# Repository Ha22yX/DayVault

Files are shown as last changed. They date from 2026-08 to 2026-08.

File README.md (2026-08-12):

<h1 align="center">DayVault</h1>

<p align="center">
  A compact wearable recorder that captures everyday speech as Ogg Opus files and transfers them to a local life archive.
</p>

<p align="center">
  <a href="README.zh-CN.md">简体中文</a> ·
  <a href="https://github.com/Ha22yX/DayVault/releases/latest">Latest release</a> ·
  <a href="Docs/README.md">Hardware docs</a> ·
  <a href="tools/dayvault_sync/README.md">Sync app</a> ·
  <a href="Docs/Serial-Command-Reference.md">Protocol</a>
</p>

<p align="center">
  
  
  
  
  
</p>

<table>
  <tr>
    <td width="50%" align="center">
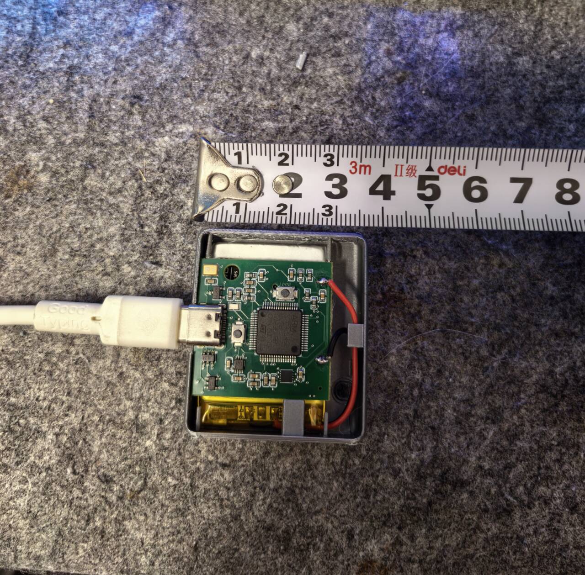
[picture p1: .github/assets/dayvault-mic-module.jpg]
Assembled DayVault recorder prototype with PCB, battery, and printed enclosure
      
      <br />
      <strong>Working hardware prototype</strong><br />
      STM32 board, battery, USB-C, microSD, and a lightweight printed enclosure.
    </td>
    <td width="50%" align="center">
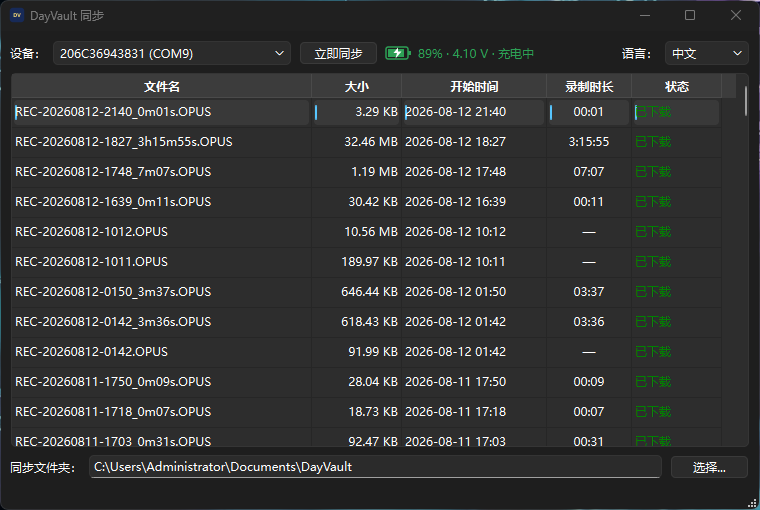
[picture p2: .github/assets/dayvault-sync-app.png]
DayVault Sync showing recordings, battery voltage, and charging state
      
      <br />
      <strong>Windows sync app</strong><br />
      Newest-first recordings, readable sizes, duration, battery level, and charging state.
    </td>
  </tr>
</table>

## What DayVault Does

DayVault is a complete personal audio-recording chain:

1. Two PDM microphones capture speech from opposite sides of a chest-worn device.
2. STM32L452 firmware adaptively fuses both channels into one 16 kHz mono stream.
3. Audio is encoded directly to Ogg Opus at a target 24 kbit/s and stored on microSD.
4. The Windows app detects the device over USB and synchronizes recordings into a folder for transcription and archiving.

No parallel WAV or raw PCM copy is kept during normal recording. At 24 kbit/s, continuous audio is roughly 260 MB per day before filesystem overhead.

## Why I Built It

I wanted a small device that could stay with me throughout the day and preserve conversations and moments I would otherwise forget. At night, I can transfer the recordings, turn them into text, and keep a searchable record of what happened.

## Current Capabilities

| Area | Implemented behavior |
| --- | --- |
| Recording | Dual SPH0655 PDM capture, adaptive fusion, 16 kHz mono Ogg Opus, 20 ms frames, 24 kbit/s target. |
| Storage | Timestamped recordings on microSD, safe finalization, resumable downloads, CRC32 verification, and circular cleanup support. |
| USB | USB-C CDC control, WinUSB bulk transfer, time synchronization, charging detection, and software or ROM DFU paths. |
| Power | Battery measurement on PA0, low-voltage protection, STOP2 sleep, RTC wake checks, and USB-aware recovery. |
| Desktop | Automatic sync, newest-first list, readable sizes, start time, duration, battery and charging display, open, locate, save-as, and confirmed deletion. |
| Enclosure | Two-part FDM-printable chest-clip enclosure with microphone and USB openings. |

## Hardware

| Subsystem | Part | Role |
| --- | --- | --- |
| MCU | STM32L452RCT6 | Audio capture, Opus pipeline, storage, USB, RTC, and power management. |
| Microphones | 2 × SPH0655LM4H-1-8 | Opposing digital PDM speech capture. |
| Storage | microSD over SPI1 | Local Ogg Opus recording storage. |
| USB | USB-C Full Speed | Sync, control protocol, charging input, and DFU. |
| 3.3 V rail | TPS63031 | Buck-boost supply from the single-cell battery. |
| Charger | MCP73831T-2ACI/OT | 4.20 V single-cell Li-ion/LiPo charging. |
| Timekeeping | STM32 RTC + 32.768 kHz crystal | Stable timestamps and low-power wake checks. |

<p align="center">
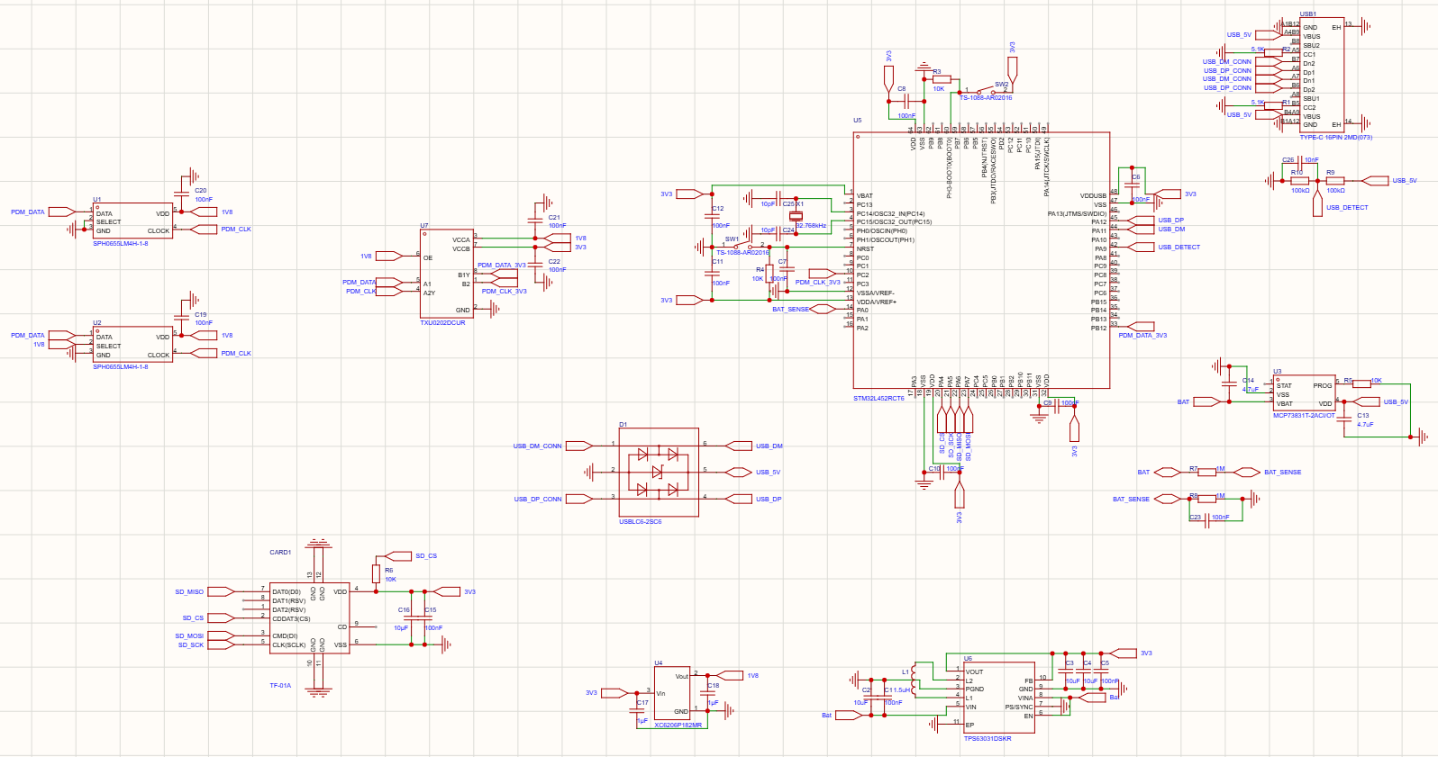
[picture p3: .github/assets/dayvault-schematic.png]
DayVault schematic
  
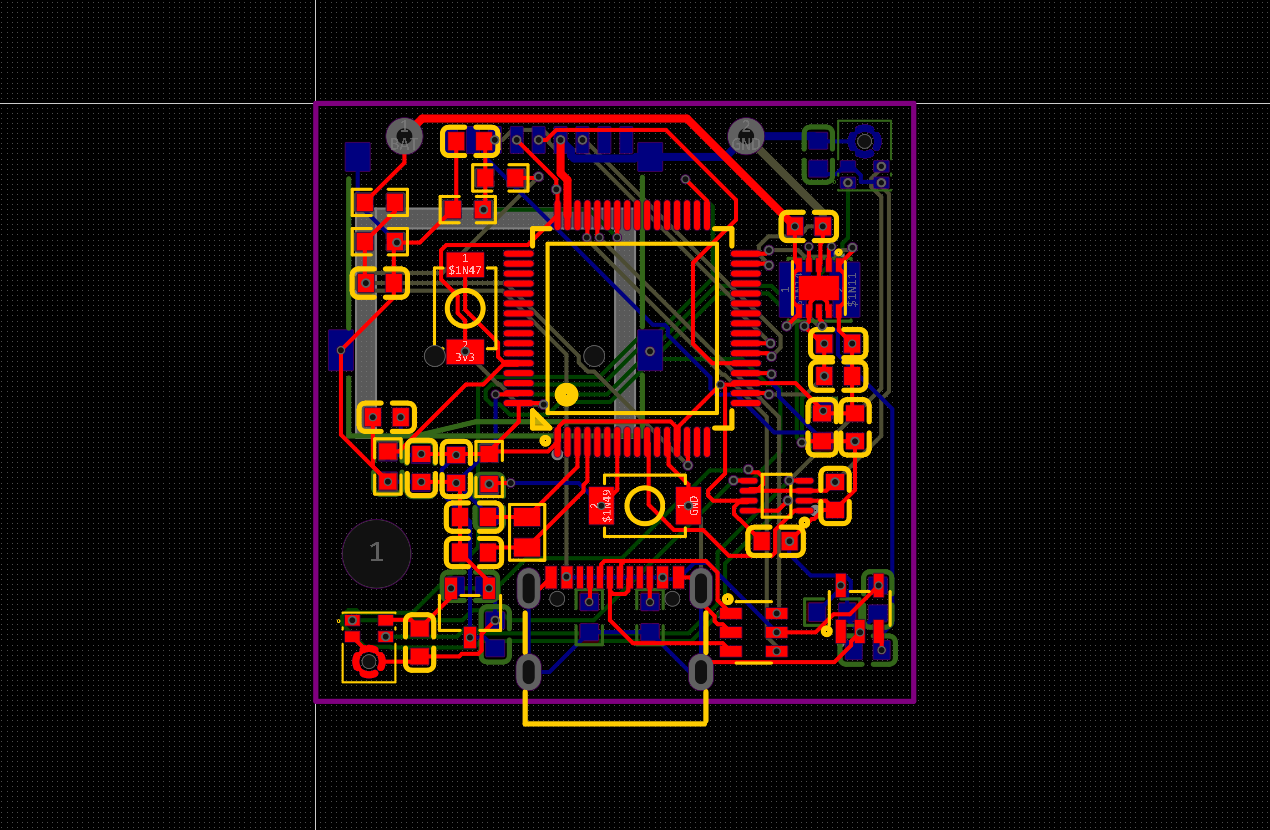
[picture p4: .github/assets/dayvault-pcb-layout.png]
DayVault PCB layout
  
</p>

## Download

The [latest GitHub Release](https://github.com/Ha22yX/DayVault/releases/latest) contains:

- <code>DayVaultSync-v1.1.1.exe</code> - packaged Windows synchronization app.
- <code>DayVault-firmware-v1.1.1.bin</code> - STM32L452 firmware image.
- SHA-256 checksums in the release notes.

Firmware updates must target DFU alternate interface 0 at <code>0x08000000</code>. Never write alternate interface 1 or the option-byte region at <code>0x1FFF7800</code>.

## Development

Run the desktop app from source:

    cd tools/dayvault_sync
    pip install -r requirements.txt
    python main.py

Build the Windows executable:

    cd tools\dayvault_sync
    build_exe.bat

Build the firmware:

    cd firmware
    platformio run -e dayvault

Run the maintained tests:

    cd tools/dayvault_sync
    python -m pytest -q

    cd ../../
    python -m pytest -q Mechanical/tests

## Repository Map

| Path | Contents |
| --- | --- |
| <code>EDA/</code> | EasyEDA project and exported hardware data. |
| <code>Docs/</code> | Hardware, pinout, battery, recording, and serial protocol documentation. |
| <code>firmware/</code> | PlatformIO STM32 firmware and native tests. |
| <code>Mechanical/</code> | Blender enclosure source, generator, tests, STL files, and renders. |
| <code>tools/dayvault_sync/</code> | PySide6 Windows synchronization app. |

## Documentation

- [Hardware overview](Docs/01-Hardware-Overview.md)
- [MCU pinout](Docs/02-MCU-Pinout.md)
- [Component pinout](Docs/03-Component-Pinout.md)
- [BOM](Docs/07-BOM.md)
- [Opus recording](Docs/09-Opus-Recording.md)
- [High-speed transfer](Docs/High-Speed-Transfer.md)
- [Serial command reference](Docs/Serial-Command-Reference.md)
- [Mechanical enclosure](Mechanical/README.md)

## Project Status

DayVault is an active hardware prototype. Recording, Opus storage, USB synchronization, battery reporting, low-voltage sleep, and the printed enclosure are working on the current board. Long-duration reliability, acoustic tuning across more wearing conditions, charging thermals, and enclosure revisions still need continued real-world testing.

## Privacy And Safety

Recording other people may require notice or consent depending on local law and context. Protect recordings and transcripts as sensitive personal data.

This is a wearable Li-ion prototype. Use a protected cell, verify polarity, test charging temperature, provide strain relief, and do not leave early hardware unattended while charging.

## License

No open-source license has been selected. Unless a license is added later, all rights remain with the repository owner.

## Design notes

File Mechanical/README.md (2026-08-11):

# DayVault Mechanical Enclosure

This directory contains the parameterized two-part chest-clip enclosure for DayVault.
The model targets a 0.4 mm-nozzle FDM printer and a 503040 LiPo battery.

## Printable parts

- `exports/DayVault_FrontCover.stl`
- `exports/DayVault_RearShell_Clip.stl`

The assembled body is nominally 46 x 40 x 15.2 mm, excluding the clip projection. Normal
walls are 1.2 mm. The integrated PETG clip remains 1.6 mm thick.

Only three external openings are present:

1. U1 forward microphone on the PCB lower-left coordinate, through the front cover.
2. U2 rear microphone on the PCB upper-right coordinate, through the rear shell.
3. Bottom USB-C charging and data port.

The microSD card, RESET, and BOOT controls require opening the enclosure.

The integrated chest clip is a true one-ended cantilever. Its upper root is fused to the
rear shell; the lower retention lip is free and keeps 0.6 mm clearance from the shell.

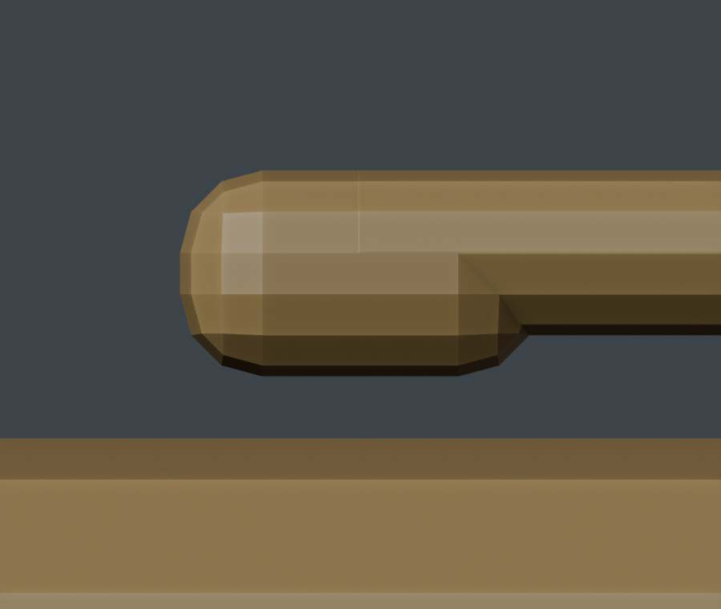
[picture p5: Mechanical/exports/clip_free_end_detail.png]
Clip free-end clearance


## Regenerating in Blender

Open Blender's scripting workspace and run:

```python
import importlib
import Mechanical.enclosure_config as ec
import Mechanical.dayvault_enclosure as dv

importlib.reload(ec)
importlib.reload(dv)
dv.build_all(r"C:\Users\Administrator\Desktop\DayVault\Mechanical")
```

The script rebuilds the complete assembly, checks each print object for manifold edges,
one connected island, positive signed volume, then saves:

- `DayVault_Enclosure.blend`
- two binary STL files
- front, rear, side, exploded, and acoustic-section PNG previews

Reference objects are named `REF_*` and are excluded from STL export.

## First print

- Material: PETG
- Layer height: 0.20 mm
- Line width: 0.40 mm
- Perimeters: 3
- Top/bottom layers: 5
- Infill: 25-35%
- Brim: 8-10 mm on the rear shell
- Supports: disabled by default
- Elephant-foot compensation: 0.15-0.20 mm if available

The exported STLs already have their intended print orientation:

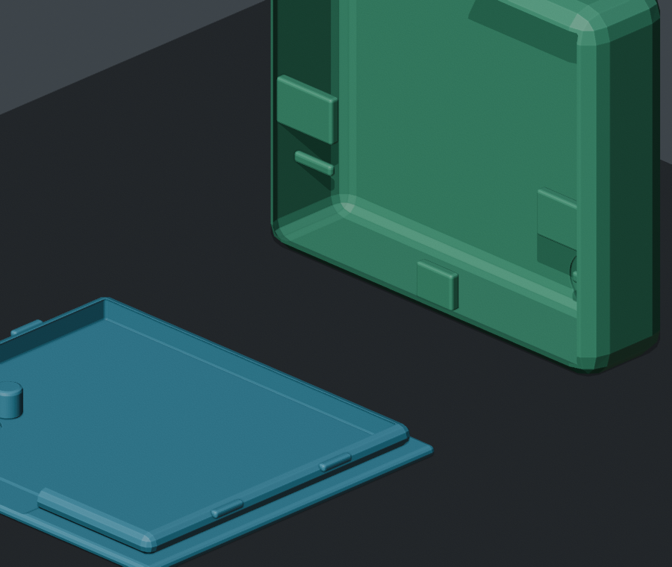
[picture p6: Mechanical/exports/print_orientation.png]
Correct print orientation


- Print the front cover with its flat outer face on the bed and the locating pin upward.
- Print the rear shell in its exported narrow-edge orientation. Its rear wall and clip
  stand vertically; the STL is approximately 46 x 14.2 x 40 mm in this orientation.
- Do not use the slicer's auto-orient feature on the rear shell and do not place its open
  cavity against the bed. That orientation creates a large unsupported bridge.
- Inspect the sliced layers before printing. No support should fill the enclosure cavity,
  clip gap, acoustic paths, or USB-C opening.

Before final assembly, check PCB edge fit, battery clearance, USB-C plug insertion, both
microphone paths, the four snap detents, and repeated clip flexing. Do not force or rigidly
compress the LiPo pouch.

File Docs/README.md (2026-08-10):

# DayVault Development Documentation

This directory describes the current DayVault hardware and serial protocol documentation.
The machine-readable hardware review artifact is `../EDA/DayVault.netlist.json`; the
EasyEDA source snapshot is `../EDA/DayVault.eprj2`.

## Reading order

1. [01-Hardware-Overview.md](01-Hardware-Overview.md) - architecture and power domains.
2. [02-MCU-Pinout.md](02-MCU-Pinout.md) - complete STM32L452RCT6 64-pin assignment.
3. [03-Component-Pinout.md](03-Component-Pinout.md) - every major component connection.
4. [07-BOM.md](07-BOM.md) - primary parts and passive values.
5. [08-Net-Map.md](08-Net-Map.md) - net-centric endpoint map for debugging and review.
6. [Serial-Command-Reference.md](Serial-Command-Reference.md) - host/device serial protocol used by firmware and the Windows sync app.
7. [High-Speed-Transfer.md](High-Speed-Transfer.md) - WinUSB protocol, fallback order, measured throughput, CRC, and resume behavior.

## Documentation rules

- `Current` means the connection exists in the exported netlist.
- `Required revision` means the EasyEDA design still needs to be changed.
- Empty MCU pins are intentionally documented as `NC`; do not connect them to ground.
- After any schematic change, regenerate the netlist and update these documents in the
  same commit.

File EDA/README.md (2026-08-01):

# EasyEDA Project Snapshot

## Files

- `DayVault.eprj2`: primary EasyEDA Pro project snapshot.
- `DayVault.netlist.json`: schematic netlist exported through the EasyEDA Pro API.
- `Backups/`: four EasyEDA automatic backups retained for recovery.

Snapshot date: 2026-08-01. The netlist uses format version 2.0.0 and contains 50 schematic
components. The API also finds 50 PCB components. The saved schematic/netlist and PCB pad
data place `PDM_DATA_3V3` on U5 PB12, while PB1 is NC; R9, R10, and C26 are present and
routed for `USB_DETECT`. Strict DRC still reports 58 clearance errors and one generic
schematic/PCB netlist mismatch, so this snapshot is not manufacturing-ready.

Do not edit the JSON as the design source. Make changes in `DayVault.eprj2`, synchronize
the PCB, rerun ERC/DRC, export a fresh JSON netlist through the API, and update `Docs/` in
the same Git commit.

## Snapshot SHA-256

```text
4365C5A7B50C0CD75C8DA6A10FFDC611223F76D3A9925CD758B8EED07B94D089  DayVault.eprj2
1E25BA79AAF0E169B6A0A0578B8C0372CAD703C3872673F63359A3E4C23DD294  DayVault.netlist.json
```

Checksums identify the current archived snapshot and must be updated whenever either file is
regenerated.

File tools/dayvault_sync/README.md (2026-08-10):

# DayVault 同步工具（Windows）

DayVault Sync 会在设备通过 USB-C 接入后校准时间、读取录音列表，并把尚未同步的文件自动导出到电脑。下载过程支持 CRC32 校验、断点续传和自动重试。

## 录音格式

同步工具识别新的 Ogg Opus 录音（`.OPUS`）和旧版 WAV 录音（`.WAV`），扩展名不区分大小写。文件会以设备提供的原始名称导出；录音元数据中的 `format` 为小写的 `opus` 或 `wav`。两种格式均使用相同的按字节传输、断点续传和 CRC32 校验流程。

## 传输方式

同步工具按以下顺序自动选择协议：

1. `BULK2`：专用 WinUSB 批量传输，默认首选。
2. `GET2`：保持 USB CDC 串口的连续传输后备方案。
3. `DL2`：兼容旧固件的传统分块协议。

`BULK2` 开始时，设备会从 CDC PID `0483:5740` 临时切换为 WinUSB PID `0483:5741`。文件校验完成并收到主机确认后，设备会自动恢复 CDC，继续同步下一个文件。

临时文件使用 `.part` 后缀。连接中断后不会删除已经接收的数据，下次从当前文件长度继续；只有在完整载荷的 CRC 校验失败时，才会回退到本次传输开始前的长度。

## 功能

- 自动发现 VID/PID `0483:5740` 的 DayVault 设备。
- 每次同步都更新 RTC 的 UTC 时间和本地时区偏移。
- 只下载新增或大小变化的录音。
- WinUSB 数据直接流式写入磁盘，不把完整录音加载到内存。
- 每个文件最多自动重试 3 次。
- 窗口关闭后驻留系统托盘，继续监听设备。
- 支持中文与英文界面。

## 源码运行

建议使用 Python 3.12 或更高版本：

```powershell
cd tools/dayvault_sync
python -m pip install -r requirements.txt
python main.py
```

`requirements.txt` 包含 PyUSB 与 `libusb-package`。后者会随应用提供 WinUSB 所需的 libusb 后端，不依赖用户手动把 DLL 放入 Python 或系统目录。

## 构建 EXE

先安装 PyInstaller，然后执行：

```bat
cd tools\dayvault_sync
build_exe.bat
```

生成文件位于 `dist\DayVaultSync.exe`。构建脚本会收集 PyUSB 后端和 `libusb-package` 中的原生库。

## 数据位置

| 路径 | 内容 |
|---|---|
| `%APPDATA%\DayVault\config.json` | 同步目录、轮询间隔、语言等配置 |
| `%APPDATA%\DayVault\state\<序列号>.json` | 每台设备已同步文件的名称与大小 |
| `%APPDATA%\DayVault\logs\app.log` | 运行和故障日志 |

录音默认下载到 `<同步目录>\<设备序列号>\`。

## 测试

```powershell
python -m pytest tools/dayvault_sync/tests -q
python tools/benchmark_winusb.py --port COM9 --timeout 45
```

当前原型的 WinUSB 实测约为 `225-227 KiB/s`。三次连续 2 MiB 压测、一个 4,508,018 字节真实录音，以及从 1,000,000 字节位置恢复的续传均通过字节数和校验验证。

## 常见问题

- **串口被占用**：关闭串口助手、其他同步工具或仍占用 COM 口的程序。
- **WinUSB 未出现**：确认固件支持 `BULK2`。工具会自动回退到 `GET2`，日志中会记录原因。
- **设备停留在 DFU**：复位设备进入正常固件；DFU 模式不会显示为 CDC 串口。
- **同步失败**：先查看 `%APPDATA%\DayVault\logs\app.log`，保留 `.part` 文件以便续传。

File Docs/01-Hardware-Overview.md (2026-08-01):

# Hardware Overview

## Purpose

DayVault is a continuously worn voice recorder. Two digital MEMS microphones feed an
STM32L452, which converts PDM audio to low-rate PCM, writes files to microSD, and exposes
recordings through USB-C. A 400 mAh single-cell Li-polymer battery is the intended source.

## Functional architecture

```mermaid
flowchart LR
    USB["USB-C"] --> ESD["USBLC6-2SC6"]
    ESD --> MCU["STM32L452RCT6"]
    USB --> CHG["MCP73831 charger"]
    CHG --> BAT["Protected 1-cell LiPo"]
    BAT --> BUCK["TPS63031 3.3 V buck-boost"]
    BUCK --> R3V3["3V3 rail"]
    R3V3 --> MCU
    R3V3 --> SD["microSD"]
    R3V3 --> LDO["XC6206 1.8 V LDO"]
    LDO --> R1V8["1V8 rail"]
    R1V8 --> MICS["2 x PDM microphones"]
    MICS --> LEVEL["TXU0202 level translator"]
    LEVEL --> MCU
    MCU --> SD
    RTC["32.768 kHz crystal"] --> MCU
    BAT --> SENSE["1 M / 1 M divider"]
    SENSE --> MCU
```

## Power rails

| Rail | Source | Consumers | Notes |
| --- | --- | --- | --- |
| `USB_5V` | USB-C VBUS | MCP73831, USB ESD clamp, USB-detect divider | Present only while USB is attached. |
| `BAT` | Protected LiPo / charger VBAT | TPS63031, battery ADC divider | Approximately 3.0 to 4.2 V. |
| `3V3` | TPS63031 | MCU, microSD, VDDUSB, level shifter, 1.8 V LDO | Converter `EN` is tied to `BAT`, so this rail is always enabled while the battery is connected. |
| `1V8` | XC6206P182MR | Both microphones and TXU0202 VCCA/OE | LDO has no enable pin. Stopping PDM clock puts microphones into sleep but does not remove power. |

## Audio path

1. STM32 `PC2/DFSDM1_CKOUT` produces `PDM_CLK_3V3`.
2. TXU0202 channel B2-to-A2 translates the clock to `PDM_CLK` at 1.8 V.
3. Both SPH0655 microphones share `PDM_CLK` and `PDM_DATA`.
4. U1 `SELECT` is low and U2 `SELECT` is high, so they drive opposite clock edges.
5. TXU0202 channel A1-to-B1 translates `PDM_DATA` to `PDM_DATA_3V3`.
6. The current schematic and PCB send data to `PB12/DFSDM1_DATIN1`; PB1 is unconnected.

This assignment supports the intended consecutive Channel 1/Channel 0 single-wire stereo
topology. It is verified in the saved design and API-exported netlist, but dual-channel
firmware and physical audio capture are still unverified. See `06-Known-Issues.md`.

## Storage path

The TF-01A microSD socket uses SPI1:

| Signal | MCU | Card pin |
| --- | --- | --- |
| `SD_CS` | PA4 | 2 / DAT3-CS |
| `SD_SCK` | PA5 | 5 / CLK |
| `SD_MISO` | PA6 | 7 / DAT0 |
| `SD_MOSI` | PA7 | 3 / CMD |

`SD_CS` has a 10 kOhm pull-up to 3.3 V. Card-detect pin 9 is currently unconnected.

## USB path

- Connector D+/D- pairs are joined by orientation into `USB_DP_CONN` and `USB_DM_CONN`.
- USBLC6-2SC6 protects both data lines and clamps to `USB_5V`/GND.
- Protected `USB_DP` and `USB_DM` connect to PA12 and PA11.
- CC1 and CC2 each use a 5.1 kOhm Rd resistor to ground, identifying DayVault as a USB sink/device.
- `USB_5V` is divided by R9/R10 to `USB_DETECT`; PA9 reads approximately 2.5 V when attached.
- C26, 10 nF from `USB_DETECT` to GND, filters insertion transients.

The MCU ROM USB DFU bootloader is selected by holding BOOT, pressing RESET, releasing
RESET, and then releasing BOOT while USB is connected.

## Charging

MCP73831 charges the single-cell battery from `USB_5V`. R5 is 10 kOhm, selecting about
100 mA nominal charge current. STAT is not connected, so charging state is not available
to firmware. The design has no system power-path/load-sharing circuit: active system
current flows from the same BAT node used by the charger and can interfere with charge
termination.

## Timekeeping

- X1 is a 32.768 kHz, 7 pF crystal on PC14/PC15.
- C24 and C25 are 10 pF load capacitors.
- STM32 VBAT is connected to 3.3 V, so RTC survives MCU Standby while 3.3 V remains alive.
- RTC time is lost after battery protection disconnects the pack or the battery is removed.
- Firmware should accept a trusted timestamp from the host whenever USB is connected.

## Battery measurement

R7 and R8 form a 1 MOhm / 1 MOhm divider from `BAT` to `BAT_SENSE`; C23 is 100 nF to
ground. PA0 measures half the battery voltage. At a 4.2 V battery, the ADC input is about
2.1 V. The source resistance is high, so use a long ADC sample time and allow at least
250 ms after power-up for the RC node to settle before relying on the first reading.

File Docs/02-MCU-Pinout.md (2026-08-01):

# STM32L452RCT6 Pinout

This file is the firmware-facing source of truth for MCU U5. The `Current connection`
column describes the saved EasyEDA project. `NC` means no electrical connection in the
schematic; it does not mean the pin may be driven arbitrarily.

## Assigned signals

| Function | Net | MCU pin | STM32 peripheral | Firmware use |
| --- | --- | --- | --- | --- |
| Battery voltage | `BAT_SENSE` | PA0, pin 14 | ADC1 input | Read the 1:1 divider using a long ADC sample time. |
| PDM clock | `PDM_CLK_3V3` | PC2, pin 10 | DFSDM1_CKOUT | Generate the microphone clock. |
| PDM data | `PDM_DATA_3V3` | PB12, pin 33 | DFSDM1_DATIN1 | Channel 1 direct input; redirect Channel 0 to the same serial input for the opposite PDM edge. |
| microSD chip select | `SD_CS` | PA4, pin 20 | GPIO output | Idle high; assert low for card transactions. |
| microSD clock | `SD_SCK` | PA5, pin 21 | SPI1_SCK | SPI mode 0 is the normal starting point. |
| microSD data to MCU | `SD_MISO` | PA6, pin 22 | SPI1_MISO | Card DO. |
| microSD data from MCU | `SD_MOSI` | PA7, pin 23 | SPI1_MOSI | Card DI/CMD. |
| USB insertion detect | `USB_DETECT` | PA9, pin 42 | GPIO input | Low without VBUS, about 2.5 V/high with VBUS. |
| USB D- | `USB_DM` | PA11, pin 44 | USB_FS_DM | Native USB Full Speed. |
| USB D+ | `USB_DP` | PA12, pin 45 | USB_FS_DP | Native USB Full Speed. |
| SWD data | none yet | PA13, pin 46 | SWDIO | Reserve for SWD test pads/header. |
| SWD clock | none yet | PA14, pin 49 | SWCLK | Reserve for SWD test pads/header. |
| RTC crystal input | internal net `$1N133` | PC14, pin 3 | OSC32_IN | X1, 32.768 kHz. |
| RTC crystal output | internal net `$1N134` | PC15, pin 4 | OSC32_OUT | X1, 32.768 kHz. |
| Reset | internal net `$1N49` | NRST, pin 7 | NRST | 10 kOhm pull-up, 100 nF to GND, pushbutton to GND. |
| ROM boot select | internal net `$1N47` | PH3/BOOT0, pin 60 | BOOT0 | 10 kOhm pull-down, pushbutton to 3.3 V. |

## Stereo PDM assignment and validation status

The saved schematic, exported netlist, and PCB now connect the shared microphone data line
to `PB12/DFSDM1_DATIN1`. PB1, pin 27, is unconnected. STM32 DFSDM single-wire stereo uses
two consecutive channels, `x` and `x-1`, fed from `DATINx`; the selected `x = 1` assignment
therefore permits Channel 1 plus redirected Channel 0.

Firmware and bring-up must still prove the topology:

1. Configure DFSDM Channel 1 for direct `DATIN1` reception.
2. Redirect Channel 0 to Channel 1's serial input.
3. Sample opposite clock edges for the two microphone SELECT phases.
4. Feed the channels through separate DFSDM filters/DMA streams and verify channel identity,
   gain, relative delay, and simultaneous capture.
5. Start with Channel 1 only if a simpler mono baseline is needed.

The design connection is complete, but two independent microphone channels must not be
claimed until firmware and assembled-hardware tests pass.

## Complete 64-pin map

| Pin | Symbol name | Current connection | Direction/use |
| ---: | --- | --- | --- |
| 1 | VBAT | `3V3` | RTC/backup-domain supply. Not raw battery voltage. |
| 2 | PC13 | NC | Spare GPIO; low drive capability restrictions apply. |
| 3 | PC14-OSC32_IN | X1/C25 | LSE input. |
| 4 | PC15-OSC32_OUT | X1/C24 | LSE output. |
| 5 | PH0-OSC_IN | NC | Main crystal input unused; internal clock is expected. |
| 6 | PH1-OSC_OUT | NC | Main crystal output unused. |
| 7 | NRST | reset RC/button | Active-low hardware reset. |
| 8 | PC0 | NC | Spare. |
| 9 | PC1 | NC | Spare. |
| 10 | PC2 | `PDM_CLK_3V3` | DFSDM1 clock output. |
| 11 | PC3 | NC | Spare. |
| 12 | VSSA/VREF- | `GND` | Analog ground/reference negative. |
| 13 | VDDA/VREF+ | `3V3` | Analog supply/reference positive. |
| 14 | PA0 | `BAT_SENSE` | ADC battery measurement. |
| 15 | PA1 | NC | Spare. |
| 16 | PA2 | NC | Spare. |
| 17 | PA3 | NC | Spare. |
| 18 | VSS | `GND` | Digital ground. |
| 19 | VDD | `3V3` | Digital supply. |
| 20 | PA4 | `SD_CS` | microSD SPI chip select. |
| 21 | PA5 | `SD_SCK` | SPI1 clock. |
| 22 | PA6 | `SD_MISO` | SPI1 MISO. |
| 23 | PA7 | `SD_MOSI` | SPI1 MOSI. |
| 24 | PC4 | NC | Spare. |
| 25 | PC5 | NC | Spare. |
| 26 | PB0 | NC | Spare. |
| 27 | PB1 | NC | Spare; former PDM data endpoint. |
| 28 | PB2 | NC | Spare/boot-related restrictions must be checked before use. |
| 29 | PB10 | NC | Spare. |
| 30 | PB11 | NC | Spare. |
| 31 | VSS | `GND` | Digital ground. |
| 32 | VDD | `3V3` | Digital supply. |
| 33 | PB12 | `PDM_DATA_3V3` | DFSDM1_DATIN1; direct Channel 1 plus redirected Channel 0. |
| 34 | PB13 | NC | Spare. |
| 35 | PB14 | NC | Spare. |
| 36 | PB15 | NC | Spare. |
| 37 | PC6 | NC | Spare. |
| 38 | PC7 | NC | Spare. |
| 39 | PC8 | NC | Spare. |
| 40 | PC9 | NC | Spare. |
| 41 | PA8 | NC | Spare. |
| 42 | PA9 | `USB_DETECT` | VBUS-presence GPIO input. |
| 43 | PA10 | NC | Spare. |
| 44 | PA11 | `USB_DM` | USB Full-Speed D-. |
| 45 | PA12 | `USB_DP` | USB Full-Speed D+. |
| 46 | PA13/JTMS/SWDIO | NC | Keep available for programming/debug. |
| 47 | VSS | `GND` | USB/digital ground. |
| 48 | VDDUSB | `3V3` | USB transceiver supply; never connect to USB 5 V. |
| 49 | PA14/JTCK/SWCLK | NC | Keep available for programming/debug. |
| 50 | PA15/JTDI | NC | Spare. |
| 51 | PC10 | NC | Spare. |
| 52 | PC11 | NC | Spare. |
| 53 | PC12 | NC | Spare. |
| 54 | PD2 | NC | Spare. |
| 55 | PB3/JTDO/TRACESWO | NC | Optional SWO; preserve if possible. |
| 56 | PB4/NJTRST | NC | Spare after debug configuration. |
| 57 | PB5 | NC | Spare. |
| 58 | PB6 | NC | Spare. |
| 59 | PB7 | NC | Spare. |
| 60 | PH3/BOOT0 | boot pull-down/button | Low for normal flash boot; high during reset for ROM loader. |
| 61 | PB8 | NC | Spare. |
| 62 | PB9 | NC | Spare. |
| 63 | VSS | `GND` | Digital ground. |
| 64 | VDD | `3V3` | Digital supply. |

## Firmware reservation rules

- Do not repurpose PA11, PA12, PA13, PA14, PB12, PC2, PC14, or PC15.
- Keep PA13/PA14 physically accessible even though USB DFU is planned; SWD is the recovery
  path for clock, option-byte, bootloader, and early-startup failures.
- Configure unused GPIOs in analog mode with no pull, unless a peripheral datasheet or board
  net requires another state.
- Configure `SD_CS` high before enabling SPI to avoid accidental card selection at boot.
- Treat the complete table above as the saved-revision truth; update it whenever the schematic
  pin assignment changes.

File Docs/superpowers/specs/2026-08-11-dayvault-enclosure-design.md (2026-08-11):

# DayVault Chest-Clip Enclosure Design

**Date:** 2026-08-11
**Status:** Approved for implementation planning
**Manufacturing process:** FDM, 0.4 mm nozzle
**Assembly:** Two printed parts: front cover and rear shell with integrated clip

## 1. Objective

Create a compact, wearable enclosure for the 30 x 30 mm DayVault PCB and a protected
503040 LiPo battery. The enclosure must preserve the opposite-facing acoustic paths of
the two SPH0655 microphones, expose USB-C, protect the electronics from clothing contact,
and print reliably on a typical FDM printer. The microSD card and both service buttons
remain internal.

The selected mechanical arrangement is an offset stack. The PCB remains upright while
the 42 x 30 x 5 mm battery is rotated horizontally and shifted downward behind the PCB.
This gives the rear microphone a clear acoustic path at the PCB's upper-right corner.

## 2. Coordinate System and Verified PCB Geometry

All XY dimensions use the PCB top-left corner as `(0, 0)` when looking at the PCB top
component layer. X increases to the right and Y increases downward. EasyEDA PCB units
were read through the live API and converted from mil to millimetres.

| Feature | PCB side | PCB coordinate | Mechanical role |
|---|---|---:|---|
| PCB outline | - | 30.000 x 30.000 mm | Primary board envelope |
| U1 SPH0655 | Top | `(2.667, 27.305)` mm | Forward/outward microphone |
| U2 SPH0655 | Bottom | `(27.534, 2.617)` mm | Rear/inward microphone |
| Existing mounting hole | Through | `(3.048, 22.606)` mm, diameter 3.4 mm | Front-cover locating pin |
| USB1 centre | Top | `(15.000, 26.162)` mm | Bottom-edge USB-C opening |
| SW1 RESET | Top | `(16.510, 20.193)` mm | Internal service control |
| SW2 BOOT | Top | `(7.493, 10.287)` mm | Internal service control |
| CARD1 microSD socket | Bottom | `(9.017, 7.112)` mm, rotation 180 degrees | Internal service access |

The SPH0655 is a bottom-port microphone. U1 is mounted on the PCB top side, so its
acoustic path exits through the PCB toward the PCB bottom side. U2 is mounted on the PCB
bottom side, so its acoustic path exits toward the PCB top side. Therefore:

- the PCB bottom side faces outward, away from clothing;
- the PCB top side faces rearward, toward the wearer and clip;
- U1 receives a front-cover sound opening at the lower-left corner;
- U2 receives a rear-shell sound channel at the upper-right corner.

This orientation is a mechanical requirement and must not be mirrored during modelling.

## 3. Overall Envelope and Stack

The nominal body envelope is **46.0 mm wide x 40.0 mm high x 15.2 mm deep**, excluding
the clip projection. External corner radius is 3.0 mm. Enclosure XY coordinates use the
body's upper-left corner as `(0, 0)`, with X right and Y down, matching the PCB coordinate
directions. The Blender modelling origin is the centre of the front outer face; positive Z
points toward the wearer. Convert enclosure XY to Blender XY only after placing all
features in the unambiguous upper-left coordinate system.

The initial stack from the outward face to the clothing side is:

| Layer | Nominal allowance |
|---|---:|
| Front wall | 1.2 mm |
| Front component and acoustic clearance | 2.0 mm |
| PCB | 1.6 mm |
| Rear component clearance | 2.8 mm minimum |
| Battery plus compression-free clearance | 5.5 mm |
| Rear wall | 1.2 mm |
| Local structural ribs | 1.2 mm minimum |

Local ribs may occupy unused XY regions, but no printed feature may press on the LiPo
pouch. The battery cavity must provide at least 0.25 mm clearance on every side and
0.5 mm across thickness. A thin removable foam pad may restrain the battery; rigid
preload against the pouch is forbidden.

## 4. Internal XY Placement

Inside the 46 x 40 mm body:

- place the PCB at enclosure coordinates `x = 8.0..38.0 mm`, `y = 2.0..32.0 mm`;
- place the battery at `x = 2.0..44.0 mm`, `y = 8.0..38.0 mm`;
- keep the U2 acoustic corridor between its global centre `(35.534, 4.617) mm` and the
  rear-shell opening free of the battery, foam, ribs, adhesive, and clip-root material;
- keep wiring in a rounded channel along the lower-left battery edge, with a minimum
  channel cross-section of 2.5 x 2.0 mm.

The battery overlaps the PCB in XY but sits behind the rear component-clearance plane.
It must rest on enclosure rails or a tray, not directly on MCU, connector, or passive
component bodies.

After applying the PCB offset, use these enclosure coordinates for modelling:

| Feature | Enclosure coordinate |
|---|---:|
| U1 forward microphone | `(10.667, 29.305)` mm |
| U2 rear microphone | `(35.534, 4.617)` mm |
| 3.4 mm PCB locating hole | `(11.048, 24.606)` mm |
| USB1 centre | `(23.000, 28.162)` mm |
| SW1 RESET | `(24.510, 22.193)` mm |
| SW2 BOOT | `(15.493, 12.287)` mm |
| CARD1 centre | `(17.017, 9.112)` mm |

## 5. PCB Retention and Enclosure Closure

Use the existing 3.4 mm PCB hole as a locating feature rather than a through-case screw
boss. A 3.0 mm diameter pin rises from the front cover and engages the PCB hole with
0.2 mm radial clearance. Engagement into the board hole is 0.8 to 1.0 mm above the PCB
bottom surface. The pin tip receives a 0.4 mm chamfer.

Three additional perimeter ledges locate the remaining PCB edges. When the enclosure is
closed, rear-shell pads clamp only bare PCB edge regions. The pads must not load solder
joints or components.

The front cover uses a continuous 2.5 mm-deep registration lip and four short snap hooks,
two on each long side. FDM assembly clearance is 0.30 mm per mating side. Hooks are
1.2 mm thick at the flexible section with a 0.6 mm retention undercut and at least 2.5 mm
root fillets. The default material is PETG; PLA is acceptable for dimensional prototypes
but not preferred for the final clip or repeated snap opening.

## 6. Acoustic Features

Each microphone uses a short, isolated acoustic passage:

- external sound opening: 2.5 mm diameter;
- internal funnel around the PCB acoustic-hole cluster: 4.5 mm diameter;
- mesh seat: 6.0 mm diameter x 0.35 mm deep;
- minimum wall around the passage: 1.2 mm.

The U1 passage is normal to the front cover at global enclosure coordinate
`(10.667, 29.305) mm`. It opens toward the room and must not be obstructed by the USB
tunnel or locating pin. Its exterior remains flush so the front cover can print flat on
its outer face.

The U2 passage starts at global enclosure coordinate `(35.534, 4.617) mm`, crosses the
rear component space without touching the battery, and exits the rear shell at the same
XY location. A 0.8 mm-high anti-blocking rim with two opposing radial air notches maintains
an air gap against clothing. The clip root must remain outside a 7.0 mm diameter keep-out
around this passage.

The two acoustic cavities must not share a printed internal chamber. A continuous wall
or the PCB itself separates them to reduce acoustic leakage between front and rear.

## 7. Connector and Service Access

### USB-C

Provide a bottom-edge tunnel aligned with USB1. The external opening is 12.0 mm wide x
5.5 mm high with 0.8 mm corner radius. The tunnel reaches the receptacle shell without a
step that can stop a USB-C plug. Maintain at least 0.5 mm clearance around the connector
metal shell and verify insertion with a plug body at least 10 mm wide.

### microSD

Do not create an external microSD slot. Card replacement requires opening the enclosure.
This leaves exactly three external passages: U1, U2, and USB-C.

### RESET and BOOT

SW1 and SW2 are service controls, not daily controls. They remain internal to avoid
accidental reset, false DFU entry, and additional clothing-facing openings. Access
requires opening the enclosure and lifting the battery from its removable restraint.
The enclosure must remain reopenable without destroying snap hooks. The physical BOOT
and RESET recovery path is retained; no firmware or option-byte change is part of this
mechanical design.

## 8. Integrated Chest Clip

The clip is part of the rear shell and is centred horizontally while staying outside the
U2 acoustic keep-out. Nominal clip geometry is:

- width: 12.0 mm;
- free length from root: 30.0 mm;
- flexible thickness: 1.6 mm;
- initial clothing gap: 1.0 mm;
- lower retention-lip projection: 0.4 mm;
- free-end clearance from rear shell: 0.6 mm;
- root fillet radius: 1.2 mm;
- arm/end rounding target: 1.4 mm.

Only the upper root is fused to the rear shell. The lower retention lip is part of the
clip arm but remains physically separated from the shell, forming a true one-ended
cantilever. The clip bends away from the rear shell when attaching the device. Its lower
end must not cover either microphone opening. Print-orientation tests must confirm that
the clip grows from its fixed root toward its free end, without support trapped in the gap.

## 9. FDM Rules

- Nominal wall thickness: 1.2 mm, equivalent to three 0.4 mm extrusion widths.
- Minimum structural rib: 1.2 mm.
- Minimum free-standing pin diameter: 2.0 mm; the PCB locator is 3.0 mm.
- Mating clearance: 0.30 mm per side for the first prototype.
- Unsupported overhang target: 45 degrees or less, except the supported clip underside.
- Internal corners receive at least 0.8 mm fillets where they affect stress or printing.
- No printed support may be trapped inside the acoustic channels or USB tunnel.

The front cover prints with its outer face on the build plate. The rear-shell STL is
pre-oriented on a narrow side wall, with the rear wall and clip standing vertically.
This avoids bridging the full enclosure cavity and gives the clip root continuous
layers that grow from the fixed root toward the free end. Use an 8-10 mm brim and disable
global supports. Never place the rear shell open-side-down. PETG is the final-material
baseline.

## 10. Deliverables

The Blender source will contain named, dimensioned objects for:

1. `DV_FrontCover`
2. `DV_RearShell_Clip`
3. `REF_PCB_30x30`
4. `REF_Battery_503040`
5. reference keep-outs for U1, U2, USB1, CARD1, SW1, SW2, and the 3.4 mm PCB hole

Export separate binary STL files for the two printed parts and keep reference objects out
of STL export. Also export a dimensioned assembly preview image.

## 11. Verification and Acceptance

Before declaring the model complete:

- confirm the front U1 and rear U2 openings are not mirrored;
- verify the 30 x 30 mm PCB and 42 x 30 x 5 mm battery fit with the stated clearances;
- run Blender non-manifold checks on both printable parts;
- confirm each STL is one watertight body with outward normals;
- confirm minimum wall and snap-hook thicknesses;
- section the assembly through both microphones, USB-C, battery, and clip root;
- verify the USB plug insertion path is unobstructed and the microSD card is reachable
  after opening the enclosure;
- verify the battery does not intersect components, locator features, or the U2 channel;
- render front, rear, side, exploded, and section views for review;
- print a first prototype at 0.20 mm layer height and validate fit before tightening
  tolerances.

The first prototype is accepted when the PCB and battery assemble without force, both
sound passages remain open, USB-C is usable, the internal microSD card remains serviceable,
the case survives repeated opening, and the clip holds the device on normal shirt fabric
without sealing the rear microphone.

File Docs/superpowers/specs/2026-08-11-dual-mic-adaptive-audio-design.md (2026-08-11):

# Dual-Microphone Adaptive Audio Design

> **Superseded audio stage (2026-08-11):** The spectral `NoiseReduction` stage described in this design was removed from the production pipeline and source tree after real recordings showed smeared speech and reduced intelligibility. The current path is adaptive fusion, speech leveling, then Opus encoding.

**Date:** 2026-08-11  
**Status:** In implementation; generic optimization scope
**Target:** DayVault STM32L452 recorder firmware

## 1. Objective

Improve speech intelligibility and reduce audible background noise while preserving the
all-day, low-power recording goal. The device is worn on the chest. One microphone faces
forward toward conversation partners and the other faces inward toward the wearer. The
wearer's voice and the forward speaker have equal priority.

The production recording remains mono. Both microphones are captured and processed
internally, then adaptively fused into one 16-bit PCM stream so storage and USB transfer
requirements do not double.

## 2. Current-State Findings

The present firmware contains the hardware setup for two DFSDM filters and two DMA
buffers, but `pdm_dma_read()` only consumes `pdm_dma_buf`. It advances the second read
position without using `pdm_dma_buf2`, so production WAV files contain only one
microphone.

The active single-channel processing chain is also too aggressive for a distant-speech
recorder:

- a 2 kHz peaking filter adds about 5 dB;
- a 3 kHz peaking filter adds about 10 dB;
- AGC can apply up to 8x gain;
- clipping occurs before and after parts of the filter chain;
- the FFT noise-reduction implementation exists but is not called by the recorder.

Analyzed recordings report sample rates around 20.97-21.07 kHz even though the public
configuration says 16 kHz and filter comments assume about 21.7 kHz. This mismatch makes
filter placement and storage estimates unreliable.

The previously observed `DUAL` result was collected while uncontrolled computer audio was
playing. It is not a silence measurement and must not be used as a microphone-noise,
sensitivity, or fault conclusion. The existing diagnostic also compares same-index DMA
samples without first proving channel synchronization. This iteration therefore uses
manufacturer limits, conservative neutral defaults, runtime counters, and deterministic
synthetic tests rather than local calibration recordings.

## 3. Constraints

- Do not modify STM32 option bytes or any DFU/boot configuration.
- Keep USB VID `0x0483` and the existing software DFU path intact.
- Preserve continuous recording and circular-delete behavior.
- Preserve the existing mono WAV contract for the sync application.
- Do not double SD storage or USB transfer volume in production mode.
- Avoid dynamic allocation in the audio path.
- Processing must not cause PDM DMA or SD ring-buffer overruns.
- Additional continuous CPU load must be measured because this is a 400 mAh wearable.

## 4. Considered Approaches

### 4.1 Equal average

Gain-match and average both microphones on every sample. This is inexpensive and can
reduce uncorrelated electronic noise by up to about 3 dB when channels observe the same
signal. It is rejected as the primary method because the microphones face opposite
directions. A fixed average can add clothing noise, weaken the better microphone, and
produce comb filtering when the two copies of one voice have different delays.

### 4.2 Fixed delay-and-sum beamforming

Align both channels for one look direction and sum them. This is rejected because a fixed
beam would favor either the wearer or the forward conversation partner, while both are
equally important. It is also a poor fit for changing head, body, and partner positions.

### 4.3 Adaptive two-sided fusion

Condition and score both channels independently, then use smoothly varying weights. A
clear forward speaker favors the forward microphone; the wearer's voice favors the inward
microphone. Correlated copies may be delay-aligned and combined, while poorly correlated
or contaminated channels are cross-faded rather than blindly summed. This is the selected
approach.

## 5. Signal-Path Architecture

```text
PDM shared data line
        |
        +--> DFSDM channel/filter A --> DMA A --+
        |                                       |
        +--> DFSDM channel/filter B --> DMA B --+--> alignment and validation
                                                --> per-channel conditioning
                                                --> frame quality analysis
                                                --> adaptive fusion
                                                --> conservative noise suppression
                                                --> speech AGC and limiter
                                                --> mono PCM ring --> WAV --> microSD
```

The audio path is separated into five testable stages. Each stage has a bypass mode so
recordings can be compared without rebuilding unrelated firmware.

## 6. Stage 1: Generic Baseline and Synthetic Validation

No local calibration recording or reminder workflow is part of this iteration. Start from
the SPH0655 clock limits and conservative channel-neutral constants. Validate the DSP with
deterministic generated signals covering clean speech-like tones, uncorrelated noise,
clipping, dropouts, delay, polarity, clothing-rub-like low-frequency bursts, and channel
level mismatch.

Runtime diagnostics report paired sample counts, overrun counters, RMS, clipping, fusion
weights, lag, and correlation without writing diagnostic audio files. Channel labels remain
neutral `A` and `B`; the firmware does not guess which physical microphone faces forward.

## 7. Stage 2: Acquisition and Channel Alignment

Configure the two consecutive DFSDM channels for opposite PDM clock edges and start their
filters in a synchronized manner. Maintain independent DMA write positions and verify that
both streams advance at the same rate. Discard the microphone/filter settling interval
after PDM clock start.

The target production PCM rate is 16 kHz because it covers speech and reduces continuous
storage and DSP work. The selected DFSDM clock-divider and oversampling combination must:

- keep the SPH0655 in its documented normal-mode clock range;
- produce a measured, stable output rate;
- use that exact rate for WAV headers and all filter coefficients.

If an exact 16 kHz rate cannot be produced from the existing clock tree without destabilizing
other peripherals, use the nearest verified rate consistently instead of patching the WAV
rate from recording duration.

Keep samples in at least 32-bit intermediate form through acquisition and filtering. Apply
saturation only at explicit output boundaries. Detect a dead, stuck, or persistently
clipped channel and fall back to the healthy channel.

## 8. Stage 3: Per-Channel Conditioning

Process each microphone independently before fusion:

- remove DC and apply an approximately 100 Hz high-pass filter;
- apply a speech-band low-pass near the Nyquist-safe upper limit;
- perform slow gain matching, constrained to a safe range such as +/-6 dB;
- track a noise estimate only during non-speech frames;
- calculate clipping, impulsiveness, low-frequency rub, and high-frequency noise penalties.

Remove the existing +5 dB and +10 dB peaking cascade. Any speech-presence EQ added later
is limited to a broad, measured boost of about 0-2 dB and is applied after the raw signal
path is known to be clean.

## 9. Stage 4: Adaptive Fusion

Use 20 ms analysis frames with quality updates every 10 ms. For each channel, estimate a
quality score from speech-band signal-to-noise ratio and subtract penalties for clipping,
clothing rub, impulsive noise, and persistent tones.

The fusion behavior is:

- when one channel has clearly better speech quality, smoothly favor it;
- when both channels contain useful but different speech, retain both with bounded weights;
- when channels are strongly correlated, estimate a small integer delay before combining;
- when correlation is weak, avoid phase-sensitive equal summation and use a soft selector;
- smooth weight changes to avoid clicks, stereo-like image jumps, and syllable pumping;
- never allow an unverified or degraded channel to dominate solely because it is louder.

Initial production weight limits are 0.10 to 0.90 rather than hard 0/1 switching. These are
tuning bounds, not final constants. A failed-channel state overrides the limits and selects
the healthy channel completely.

Because the microphones face opposite directions, this block is a two-sided speech selector
and mixer, not a fixed beamformer.

## 10. Stage 5: Noise Suppression, AGC, and Limiting

Run noise suppression after fusion so the expensive spectral stage processes one stream.
Start with a conservative mode:

- update the noise spectrum only in confidently non-speech frames;
- smooth gains over both time and neighboring frequency bins;
- keep the spectral gain floor around 0.20-0.30;
- limit maximum attenuation to avoid musical noise and isolated noise speckles;
- retain a volatile bypass mode for runtime diagnosis.

The existing 0.06 gain floor is too aggressive for the desired natural conversation sound.
The implementation may use an optimized CMSIS-DSP FFT or a lower-cost fixed-point path,
but only after measuring CPU time and stack/RAM use.

Apply AGC after noise suppression:

- use speech-gated level estimation;
- freeze or release gain slowly during silence;
- target a natural speech level rather than a constant peak;
- limit make-up gain initially to about 4x;
- use fast peak limiting near -1 dBFS;
- count every limiter activation and hard clip for diagnostics.

## 11. Mechanical Noise Requirement

The inward microphone port must not rub directly against clothing. The enclosure or clip
must maintain an air gap and use an acoustically transparent barrier that does not seal the
port. Firmware can recognize and reduce some low-frequency rub, but it cannot recover
speech masked by direct mechanical contact.

## 12. Runtime Diagnostics

Extend diagnostics without changing normal recording commands:

- report both raw RMS/peak/DC values;
- report measured channel lag and correlation confidence;
- report current fusion weights and channel-fault flags;
- report estimated noise level, AGC gain, limiter count, and processing time;
- retain `RAW` and `DUAL` compatibility where practical;
- provide sample-rate and audio-pipeline status commands that do not create recordings.

Diagnostic commands must not block the recorder long enough to overrun DMA.

## 13. Acceptance Tests

### Functional

- Both microphone DMA streams contain independent, valid audio.
- Production WAV remains mono and is accepted by the existing sync application.
- USB, DFU, RTC filenames, circular deletion, and low-battery behavior are unchanged.
- One failed microphone still produces a valid recording from the other microphone.

### Audio

- Synthetic normal-level speech cases produce no hard clipping.
- Deterministic noise-only fixtures are attenuated by at least 6 dB after the learning
  interval while clean speech correlation remains above 0.95.
- In clean-A/noisy-B and clean-B/noisy-A fixtures, the clean channel receives the larger
  fusion weight without completely suppressing a second healthy channel.
- No obvious pumping, clicking, comb-filter coloration, or musical-noise speckles.
- Fixed tonal interference is removed at its acquisition source where possible; a notch is
  added only when a repeatable raw-capture tone remains.
- Speech-to-text output on the same test script improves or does not regress for both
  directions.

### Performance and power

- Zero PDM DMA and audio ring overruns during a one-hour stress recording.
- DSP processing has measured headroom during worst-case SD activity.
- Continuous current is measured before and after; an unexplained increase is a release
  blocker.
- At 16 kHz, mono 16-bit PCM remains about 2.76 GB per 24 hours instead of doubling for
  stereo storage.

## 14. Delivery Sequence

1. Expose paired DFSDM data and exact rate helpers.
2. Synchronize both DFSDM filters and put the PDM clock inside the microphone limits.
3. Implement adaptive two-sided fusion and failed-channel fallback with synthetic tests.
4. Replace aggressive EQ/AGC with conservative noise reduction and level control.
5. Integrate the mono production path and add lightweight runtime statistics.
6. Build only after targeted regression, memory, timing, and static safety checks pass.

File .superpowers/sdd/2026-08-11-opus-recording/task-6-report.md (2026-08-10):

# Task 6 Report: Direct Production Ogg Opus Recording

Date: 2026-08-11
Branch: `codex/dual-mic-audio`
Baseline: `834ca73 fix(audio): release failed pipeline ownership`

## Scope

Task 6 replaces only the production continuous recorder with direct mono Ogg Opus at
16 kHz and a target 24 kbit/s. Diagnostic commands that intentionally create WAV test
captures remain intact. No PCM or WAV file is created alongside a production recording.

The production path is now:

`pdm_dma_read_dual -> AudioPipeline -> DayVaultOpusEncoder -> OggOpusWriter -> FatFs`

## RED Evidence

1. Source contract before implementation:

   `python -m pytest tools/dayvault_sync/tests/test_firmware_memory.py -q`

   Result: 2 failed, 9 passed. The expected failures were the absent
   `CompressedRecorder.cpp` paired-Opus path and the temporary
   `dayvault_opus_encoder_link_probe` still present in PlatformIO and the encoder adapter.

2. Immediate one-second Ogg page behavior before implementation:

   `pio test -e native -f test_ogg_opus`

   Result: 2 failed, 11 passed. Packet 50 left only the two header pages, and the configured
   sink failure did not occur until packet 51.

3. Narrow DSP diagnostics contract before implementation:

   `pio test -e native -f test_audio_pipeline`

   Result: compile failure because `AudioPipelineStats` had no fusion, noise-reduction, or
   leveler snapshots.

## GREEN Evidence

- Source contracts: 13 passed.
- Ogg Opus writer: 13 passed, including immediate packet-50 page output and same-granule
  empty EOS for an exact page boundary.
- Audio pipeline: 11 passed, including the new DSP snapshot contract.
- Real encoder SRAM2 partition: passed with a 24 KiB encoder limit while retaining a
  non-overlapping 8 KiB Ogg page region.
- Focused native matrix: PDM rate/ring, Opus arena/encoder, Ogg writer, pipeline, fusion,
  noise reduction, and leveler all passed.
- ARM build: `pio run -e dayvault -j 1` succeeded.
- `git diff --check` succeeded; line-ending conversion warnings are repository-local Git
  policy warnings, not whitespace errors.

## Implementation

- Added `CompressedRecorder`, a fixed-memory state machine with explicit result codes and
  current/last statistics.
- Start is transactional: mount, circular deletion, free-space verification, `.OPUS`
  creation, encoder setup, non-overlapping page reservation, Ogg header writes, header
  sync, DSP reset, PDM start, and 32 paired startup samples discarded. Any failure stops
  PDM if needed, releases pipeline/encoder state, closes, and deletes the incomplete new
  file.
- Poll reads at most 128 paired samples. Frames are encoded at the existing fixed Opus
  configuration and passed to Ogg with exact valid-sample counts.
- Packet 50 immediately writes the completed one-second page. Checkpoint waits until a new
  page exists, then calls `f_sync`, avoiding a premature one-second sync that would delay
  durability until the next interval.
- Stop halts PDM, drains paired samples, finishes DSP padding/trimming, writes EOS, syncs,
  closes, ends the encoder, and then renames timestamp files using
  `valid_input_samples / 16000`.
- New sequence and timestamp names use `.OPUS`. Circular deletion accepts `.OPUS` and
  legacy `.WAV` case-insensitively and continues to skip the active basename.
- `GET2`, `DL2`, `BULK2`, `BULKSPEED`, `SDSPEED`, and `SPEED` stop/finalize recording before
  claiming SRAM2. Production start refuses while that workspace is leased.
- Added `OPUSSTAT` without file or PDM side effects. It reports bitrate, sample rate,
  frames, pages, valid samples, bytes, encoder errors, maximum encode time, workspace use,
  paired overruns, fusion weights/faults, NR state/gain, and leveler gain/limiter count.
- Removed the temporary linker-retention flag and probe function. Production references
  root the codec naturally.
- Added `-fstack-usage` so ARM stack reports remain reproducible.

## Resource Audit

From `arm-none-eabi-size -A firmware.elf` and the linker map:

| Resource | Used | Limit | Remaining |
| --- | ---: | ---: | ---: |
| Flash (PlatformIO) | 218,120 B | 262,144 B | 44,024 B |
| SRAM1 data + BSS + noinit | 71,216 B | 131,072 B | 59,856 B |
| SRAM1 including 1,536 B linker heap/stack reservation | 72,752 B | 131,072 B | 58,320 B |
| SRAM2 `.ram2` workspace | 32,768 B | 32,768 B | 0 B statically |

SRAM2 is intentionally shared, not simultaneous: encoder arena and Ogg page while
recording, transfer buffers while exporting. The real-codec host test proves the encoder
starts within the 24 KiB limit and leaves the 8 KiB page region non-overlapping.

## Stack Audit

The clean ARM build generated 356 `.su` files. Relevant worst entries include:

- `silk_encode_frame_FIX`: 10,752 B, dynamic.
- `silk_pitch_analysis_core`: 1,016 B, dynamic.
- `opus_encode_native`: 880 B, dynamic.
- `loop`: 4,968 B, static.
- `CompressedRecorder::encode_frame`: 24 B, static.
- `DayVaultOpusEncoder::encode`: 24 B, static.

A conservative simultaneous recording call-path sum includes the full `loop` frame,
recorder/pipeline callback frames, Opus wrappers, restricted-SILK frame storage, and the
deepest pitch branch: approximately 18,656 B. Subtracting this from the 58,320 B remaining
after static sections and linker reservation leaves approximately **39,664 B** conservative
SRAM1 headroom, exceeding the required 8 KiB by 31,472 B. Interrupt stack use is not fully
represented by `.su`, but this margin is large relative to the requirement.

## Symbol Audit

Present in the final ELF:

- `CompressedRecorder::{start,poll,checkpoint,stop}`
- `DayVaultOpusEncoder::{begin,encode,end}`
- `OggOpusWriter::{begin,add_packet,finish}`
- `opus_encode`, `opus_encode_native`, `silk_Encode`, `silk_encode_frame_FIX`
- `g_transfer_workspace` at `0x10000000`, size `0x8000`

Absent from the final ELF/source configuration:

- `dayvault_opus_encoder_link_probe`
- Opus decoder creation symbols
- DNN, DRED, and OSCE symbols
- libc `malloc`, `calloc`, or `realloc` references from `libopus.a`; the archive references
  the DayVault arena hooks instead.

## Safety Scan

- No `0x1FFF7800` reference was found in firmware source.
- No `FLASH_OPTR`, option-byte programming, or boot-bit modification was found.
- Software DFU remains `SYSTEM_MEMORY_BASE 0x1FFF0000u`.
- USB VID remains `0x0483` in the board metadata and WinUSB descriptors.
- Production `CompressedRecorder` contains no `wav_build_header`, `f_lseek`, mono
  `pdm_dma_read`, or parallel PCM/WAV write path.
- Intentional WAV diagnostics remain in `main.cpp`.
- No flashing, serial session, microphone capture, or board access was performed.

## Self-Review

- Startup cleanup covers failures before and after file creation, header writes/sync,
  pipeline ownership, PDM start, and paired discard.
- Ogg write callbacks check both `FRESULT` and exact byte count.
- Checkpoint does not seek or rewrite headers and cannot mark a checkpoint complete before
  a new audio page is written.
- Error stops preserve the latest durable prefix and never fall back to WAV.
- Low-battery stop and USB attach/detach still route through the production stop/start
  wrappers. The main loop continues to service the watchdog.
- Timestamp collision suffixes and RTC-unset sequence naming are preserved with `.OPUS`.
- Shared SRAM2 ownership is explicit for all named transfer and benchmark paths.

## Concerns And Follow-Up

- Per instruction, this pass did not exercise a physical board, microphones, serial port,
  DFU, or flashing. `OPUSSTAT max_us` and real-time overrun behavior still require a later,
  separately authorized hardware validation pass.
- The upstream fixed-point libopus build emits existing GCC warnings around float-cast
  fallbacks and a SILK zero-length-array diagnostic; native codec tests and the ARM link
  succeed, and these warnings were not introduced by Task 6.
- The linker emits its existing RWX load-segment warning. Section limits and symbols were
  inspected directly, but linker permission cleanup is outside Task 6.
- FatFs startup failure branches are source-reviewed and transactionally implemented; no
  native fake-FatFs fault-injection harness exists in this task.

## Commit

Requested commit message: `feat(rec): save production audio directly as Opus`

---

## Independent Review Fix Round 1/5

Date: 2026-08-11
Review input: `.superpowers/sdd/2026-08-11-opus-recording/task-6-independent-review.md`

All one Critical, five Important, and one Minor findings were addressed. This round did
not access hardware, serial, microphones, USB devices, DFU, option bytes, or flashing.

### RED Evidence

1. Ogg final boundary: `pio test -e native -f test_ogg_opus` produced 2 expected
   failures and 13 passes. The new 49-full-plus-short and 49-full-plus-zero tests observed
   50 packets on the non-EOS page instead of the required 49.
2. Encoder lookahead: `pio test -e native -f test_opus_encoder` failed to compile because
   the new `OpusFinalization.h` contract and 16 kHz lookahead getter did not exist.
3. Frozen PDM drain: `test_pdm_ring` failed to compile on the absent frozen-pair helper;
   the source suite reported 1 failure and 13 passes because no atomic freeze API existed.
4. Cleanup and rename: `test_recording_name` failed to compile on the absent bounded name
   formatter; source contracts reported 2 failures and 14 passes for missing cleanup state
   and final-destination collision probing.
5. Diagnostics: source contracts reported 1 failure and 16 passes at the first unguarded
   `DMAT` branch. The normal-close/OPUSSTAT extension subsequently reported 1 expected
   failure and 16 passes before those details were corrected.

### GREEN Evidence

- Source contracts: 17 passed.
- Focused native matrix: 82 passed across PDM rate/ring, Opus arena/real encoder, Ogg,
  audio pipeline, fusion, noise reduction, leveler, and recording-name policy.
- ARM build: `pio run -e dayvault -j 1` succeeded in 55.04 seconds.
- `git diff --check` passed; Git emitted only the repository's line-ending policy warnings.

### Fixes

- Ogg keeps an ordinary full packet 50 immediate. A short or zero-valid packet that would
  occupy slot 50 first flushes the prior 49 full packets, then remains with all following
  padding packets on the EOS page. Tests validate CRC, page flags, sequence numbers,
  packet counts, and exact nondecreasing granules. The corrected one-second case uses
  `50 * 320` captured samples and granule `312 + 16000 * 3 = 48312`.
- `DayVaultOpusEncoder` exposes the native 16 kHz lookahead and derives 48 kHz pre-skip as
  exactly three times that value. A pure finalization planner subtracts zero padding already
  present in a partial 320-sample frame, then requests enough additional all-zero frames to
  cover the remaining delay. Recorder padding packets use `valid_samples = 0`, so EOS
  granule remains the captured-input duration and cannot retreat behind a prior page.
- `pdm_stop_and_freeze()` runs under the IRQ lock, stops both DFSDM writers, accounts
  pending TC flags into exact paired producer snapshots, freezes those counters, and only
  then disables DMA/IRQs and clears residual flags. Frozen paired reads use zero margin;
  the pure ring test proves the final 64 samples withheld from a live writer are drainable.
- Failed-start cleanup now records the primary failure separately from close/unlink cleanup
  failure, clears each ownership flag only after its FatFs operation succeeds, and retries
  pending cleanup before any later start resets state. OPUSSTAT exposes primary, cleanup,
  and reported outcomes. Normal close failures also retain truthful open state.
- Every PDM claimant (`DMAT`, `ITST`, `SAMP`, `CAPT`, `DSCAN`, `NF`, `DUAL`, `RAW`)
  finalizes an active production recording before reconfiguration. All blocking diagnostic
  acquisition and scan loops service IWDG, including CAPT and DSCAN. Intentional diagnostic
  WAV capture remains unchanged apart from ownership and watchdog handling.
- Timestamp recording keeps one stable RTC stem. Final rename searches with `f_stat` for a
  free destination and places collision syntax before duration, for example
  `REC-20260811-143025_2_1m02s.OPUS`, before calling `f_rename`.

### Resource And Symbol Audit

Fresh `arm-none-eabi-size -A` and linker-map results:

| Resource | Used/reserved | Limit | Remaining |
| --- | ---: | ---: | ---: |
| Flash (PlatformIO) | 219,288 B | 262,144 B | 42,856 B |
| SRAM1 `.data + .bss + .noinit` | 71,880 B | 131,072 B | 59,192 B |
| SRAM1 including 1,536 B heap/stack linker reservation | 73,416 B | 131,072 B | 57,656 B |
| SRAM2 `.ram2` transfer workspace | 32,768 B | 32,768 B | 0 B static |

`g_transfer_workspace` remains at `0x10000000`, size `0x8000`. Required production
symbols remain in the ELF: recorder start/poll/checkpoint/stop, encoder begin/encode/end,
Ogg begin/add/finish, `opus_encode_native`, `silk_Encode`, and
`silk_encode_frame_FIX`. Decoder creation, DNN/DRED/OSCE, and temporary linker-probe
symbols are absent. The Opus archive has no malloc/calloc/realloc dependency and uses only
the DayVault arena free hook; unrelated framework libc allocator symbols remain in the ELF.

### Stack Audit

The clean ARM build generated 358 `.su` files. Relevant entries include:

- `loop`: 4,968 B static.
- `rec_stop`: 248 B static.
- `CompressedRecorder::stop`: 24 B static.
- `CompressedRecorder::drain_encoder_lookahead`: 24 B static.
- `opus_encode_native`: 880 B dynamic.
- `silk_Encode`: 184 B dynamic.
- `silk_encode_frame_FIX`: 10,752 B dynamic.
- `silk_pitch_analysis_core`: 1,016 B dynamic.

The observed deepest recording path sums to about 18.5 KiB. Rounding this upward to a
19 KiB conservative runtime allowance leaves `57,656 - 19,456 = 38,200 B` SRAM1 stack
headroom, exceeding the required 8 KiB by 30,008 B. Interrupt usage is not fully described
by GCC `.su` files, but it is covered comfortably by this remaining margin.

### Safety And Compatibility Scan

- No firmware/config reference to `0x1FFF7800`, `FLASH_OPTR`, boot option bits, or option-
  byte programming APIs was found.
- Software DFU remains `0x1FFF0000u`; USB VID remains `0x0483` in board and descriptor
  sources.
- Production `CompressedRecorder` contains no `wav_build_header`, `f_lseek`, mono
  `pdm_dma_read`, PCM file, or parallel WAV path.
- Legacy `.WAV` circular deletion compatibility remains case-insensitive alongside the
  configured `.OPUS` extension.
- Transfer-workspace exclusion, low-battery finalization, USB attach/detach recording
  behavior, and temporary-probe removal remain intact.

### Self-Review And Concerns

- Ogg boundary behavior was checked for full packet 50, short packet slot 50, zero-valid
  padding slot 50, exact EOS flags, CRCs, sequences, and monotonic granules.
- Lookahead planning covers exact-frame, partial-frame, already-sufficient partial padding,
  and empty-input cases. Empty input does not invent an Opus audio packet.
- PDM ordering was reviewed statically: DFSDM production is halted while IRQs are locked,
  TC flags are accounted by the existing double-snapshot logic, and frozen counters are
  stored before DMA disable/final clear. No hardware run was performed.
- FatFs failure handling is source-contracted rather than native fault-injected because the
  firmware currently has no fake FatFs harness. Close/unlink transitions and deterministic
  retry paths were reviewed directly.
- The upstream fixed-point Opus warnings and existing RWX load-segment warning remain; this
  round introduced no new compiler or linker failures.
- Real-time encode latency and physical stop-boundary capture still need a separately
  authorized hardware validation pass. This round intentionally performed none.

---

## Independent Review Fix Round 2/5

Date: 2026-08-11
Review input: `.superpowers/sdd/2026-08-11-opus-recording/task-6-rereview-1.md`

The remaining combined Ogg final-boundary Critical was reproduced and fixed. No hardware,
serial, microphone, USB-device, DFU, option-byte, or flashing operation was performed.

### RED Evidence

Added `test_short_then_lookahead_at_page_boundary_stay_together_on_eos` with the exact
production-reachable sequence: 48 full 320-valid packets, one 300-valid short packet, and
one zero-valid lookahead packet. Before the production change, focused Ogg testing reported
1 failed and 15 passed; the new test failed immediately after the short packet with
`Expected 3 Was 2`, proving the writer had not separated the 48 complete packets before
entering finalization.

### Implementation

`OggOpusWriter::add_packet()` now flushes buffered ordinary packets only on the transition
to the first final packet (`final_packet && !final_packets_started_`). It performs that
transition before appending the short packet. Once `final_packets_started_` is true, later
short or zero-valid packets are buffered with the first final packet until `finish()` emits
their shared EOS page, including when their combined packet count reaches the normal
50-packet rollover boundary. Ordinary full packet 50 still flushes immediately.

The combined regression validates:

- Sequence 2 is non-EOS and contains exactly 48 full packets.
- Sequence 2 granule is `312 + 48 * 320 * 3 = 46392`.
- Sequence 3 has EOS set and contains the short and lookahead packets as two laces.
- Sequence 3 granule is `312 + (48 * 320 + 300) * 3 = 47292`.
- Packet payload placement, page lengths, sequence numbers, flags, monotonic granules, and
  all page CRCs are correct.

The existing rollover sink-failure fixture used `valid_samples = 160` despite intending to
exercise ordinary full-frame packet 50. It was corrected to 320 so it continues to test the
production rollover path rather than finalization behavior.

### GREEN Evidence

- Focused Ogg writer: 16 passed.
- Real libopus encoder/finalization: 9 passed.
- Complete focused native matrix: 83 passed.
- Source contracts: 17 passed.
- ARM: `pio run -e dayvault -j 1` succeeded.
- `git diff --check` passed with only repository line-ending policy warnings.

### Resource, Symbol, Stack, And Safety Audit

- Flash: 219,284 B of 262,144 B, leaving 42,860 B.
- SRAM1 `.data + .bss + .noinit`: 71,880 B. Including the 1,536 B linker
  heap/stack reservation leaves 57,656 B before runtime stack.
- SRAM2 remains exactly 32,768 B at `0x10000000` for the shared transfer workspace.
- The conservative 19 KiB recording call-path allowance remains unchanged and leaves
  38,200 B SRAM1 headroom, exceeding the required 8 KiB by 30,008 B.
- Recorder, Ogg, encoder, `opus_encode_native`, `silk_Encode`, and
  `silk_encode_frame_FIX` symbols remain present. Decoder and temporary linker-probe
  symbols remain absent.
- No `0x1FFF7800`, option-byte programming, boot-option mutation, production
  `wav_build_header`, production `f_lseek`, or mono production PDM read was found.
- Software DFU remains `0x1FFF0000u`; USB VID remains `0x0483`; `.OPUS` production and
  legacy `.WAV` deletion compatibility remain intact.

### Self-Review And Concern

The mutation guarded by the new test is removing the first-final state check or allowing a
later final packet to preflush a page that already contains a short packet. Either change
breaks the asserted page count/flags before EOS. Physical decoder interoperability and
stop-boundary timing remain for a separately authorized hardware pass; none was attempted.

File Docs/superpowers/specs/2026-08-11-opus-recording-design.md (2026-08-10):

# DayVault Opus Recording Design

## Goal

Store production recordings directly as standard Ogg Opus files at a target bitrate of
24 kbit/s. The recorder must not create or retain a parallel PCM/WAV original. The change
must preserve dual-microphone capture, adaptive mono fusion, noise reduction, level control,
timestamped names, circular deletion, low-battery finalization, and USB export.

## Constraints

- MCU: STM32L452RCT6, Cortex-M4 at 80 MHz, 256 KiB Flash, 128 KiB SRAM1 + 32 KiB SRAM2.
- Baseline firmware: 75,788 bytes Flash, 59,412 bytes SRAM1 BSS/data, and all 32 KiB SRAM2
  reserved by the USB transfer workspace.
- Opus accepts 8, 12, 16, 24, or 48 kHz input. The existing measured configuration produces
  about 16,026 Hz and therefore cannot be passed to an Opus encoder as exact 16 kHz audio.
- Normal recording is mono after the two microphone streams have been fused.
- The device may lose power while recording. Every durable prefix must remain a valid,
  recoverable Ogg stream even when the final EOS page is absent.
- No option bytes, boot configuration, DFU address, or USB VID may change.

## Approaches Considered

### 1. Standard Ogg Opus using the Xiph reference encoder (selected)

Vendor the official libopus 1.6.1 source under its BSD license, build fixed-point encoder
code without floating-point APIs or neural extensions, and write RFC 7845 Ogg Opus pages.
This produces files accepted directly by FFmpeg, VLC, browsers, and speech-to-text tooling.

### 2. Custom length-prefixed raw Opus packets

This is smaller to implement but produces a DayVault-specific container. Every consumer
would require a custom demuxer, seeking would be poor, and files would not be ordinary
`.opus` files. This approach is rejected.

### 3. Keep WAV and transcode on the computer

This minimizes MCU work but retains roughly 2.76 GB/day of PCM and violates the requirement
to save only the compressed recording. This approach is rejected.

## Audio Format

- Container: Ogg Opus, RFC 7845, extension `.OPUS`.
- Codec implementation: official Xiph libopus 1.6.1, pinned and checksummed.
- Input: one channel, signed 16-bit PCM, exactly 16,000 samples/s.
- Frame duration: 20 ms, 320 samples per Opus packet.
- Application: restricted SILK speech mode. Output packets remain standard Opus packets.
- Rate control: constrained VBR, target 24,000 bit/s.
- Complexity: 3 initially, selected for the all-day power budget. Runtime diagnostics expose
  worst encoding time so this can be raised only after measured headroom is known.
- DTX: disabled so low-level and distant speech is not intentionally discarded.
- In-band FEC and packet-loss redundancy: disabled because storage is reliable local media.
- Maximum packet allocation: 160 bytes. Bitrate is controlled by the encoder CTL, not by this
  safety bound.

At 24 kbit/s, codec payload is about 259.2 MB per 24 hours. Ogg page headers and metadata add
roughly a few megabytes per day, so a practical estimate is about 265 MB/day before filesystem
allocation overhead. Actual constrained-VBR size varies with content.

## Exact Capture Rate

Change the DFSDM output clock divider from 52 to 50 and the Sinc3 oversampling ratio from 96
to 100:

```
80,000,000 / 50 = 1,600,000 Hz PDM clock
1,600,000 / 100 = 16,000 Hz PCM
```

The 1.6 MHz PDM clock remains inside the SPH0655 normal operating range. One rate definition
continues to drive DFSDM setup, DSP coefficients, Opus setup, duration accounting, and tests.

## Data Flow

```
PDM DMA A/B
  -> paired 128-sample blocks
  -> adaptive fusion
  -> noise reduction (128-sample latency)
  -> speech leveler
  -> 320-sample Opus frame assembler
  -> libopus encoder
  -> Ogg page accumulator
  -> FatFs / TF card
```

The recorder drains paired DMA samples without blocking. A fixed-memory pipeline accepts
arbitrary read lengths, preserves channel pairing, and emits complete 128-sample DSP blocks.
The resulting mono stream is accumulated into 320-sample codec frames. Stop pads only the
encoder input needed to finish the final frame; the final Ogg granule position trims those
padding samples so playback duration matches real captured samples.

## Ogg Layout and Durability

1. Write and sync an `OpusHead` BOS page.
2. Write and sync an `OpusTags` page identifying DayVault and the encoder version.
3. Accumulate 50 packets (one second) per audio page. Each page has a valid Ogg CRC and a
   48 kHz granule position.
4. Write each completed page with one checked FatFs write.
5. Call `f_sync` at least once per second, after a completed page.
6. On clean stop, encode the partial final frame with zero padding, use the exact original
   sample count for end trimming, flush an EOS page, sync, close, and append duration to the
   filename.

On abrupt power loss, only an in-memory partial page can be lost. All previously synced pages
remain structurally complete. Many decoders accept a stream without an EOS page; a future
repair tool can add EOS without transcoding if needed.

## Memory Strategy

No per-frame allocation is permitted. The encoder state, Ogg page buffer, PCM frame, DSP
blocks, and packet buffer all use fixed storage. Recording and USB bulk export are mutually
exclusive, so the existing contiguous 32 KiB SRAM2 transfer workspace may be reused by the
encoder and page buffer while recording. Startup checks the actual libopus restricted-SILK
state size and fails recording cleanly if the pinned build no longer fits.

The firmware build is rejected if Flash exceeds 256 KiB or if static SRAM sections exceed
their linker regions. Stack-usage reports for codec entry points are inspected because
libopus uses variable-length scratch arrays in the fixed-point build.

## File and Protocol Changes

- Production names become `REC-YYYYMMDD-HHMM.OPUS` and
  `REC-YYYYMMDD-HHMM_HhMmSs.OPUS`, with the existing collision suffix behavior.
- RTC-unset fallback names become `REC001.OPUS` through `REC999.OPUS`.
- Circular deletion recognizes both new `.OPUS` files and legacy `.WAV` files, and never
  deletes the active file.
- `LIST`, `GET2`, `BULK2`, and WinUSB remain byte-oriented and require no wire-format change.
- The Windows sync parser and UI recognize and sort `.OPUS` recordings while retaining
  legacy `.WAV` compatibility.
- Add `OPUSSTAT` diagnostics for configured bitrate, frame/page counts, encoded bytes,
  encoder failures, maximum encode time, DMA overruns, and DSP state. It never records audio.

## Error Handling

- If encoder initialization, header writing, page writing, or syncing fails, stop PDM,
  close the file, preserve the last durable prefix, report a specific recorder error, and do
  not create a WAV fallback.
- If DSP cannot keep up, DMA overrun counters expose the loss. The recorder never silently
  changes codec bitrate or sample rate.
- Low battery uses the same clean finalization path before STOP mode.
- USB export commands first stop/finalize recording before borrowing the shared SRAM2
  workspace.

## Tests and Acceptance

- Golden tests for Ogg CRC, `OpusHead`, `OpusTags`, lacing, sequence numbers, granule
  positions, final trimming, and EOS.
- Real libopus host test: encode deterministic PCM and verify every return code and packet
  bound.
- Pipeline tests: arbitrary paired input chunking, NR latency flush, 320-sample framing, and
  exact final sample accounting.
- Filesystem/name tests accept `.OPUS` and legacy `.WAV`.
- Sync parser tests cover timestamp, collision, duration, sequence, and both extensions.
- Firmware build and linker map stay within Flash/SRAM limits.
- Static safety scan confirms no option-byte writes, System Memory remains `0x1FFF0000`, and
  USB VID remains `0x0483`.
- No board flashing, microphone sampling, or environmental recording is part of this
  implementation pass.

## References

- Xiph libopus 1.6.1 release: https://opus-codec.org/release/stable/2026/01/14/libopus-1_6_1.html
- Opus API 1.6: https://opus-codec.org/docs/opus_api-1.6.pdf
- Ogg Opus encapsulation: https://www.rfc-editor.org/rfc/rfc7845

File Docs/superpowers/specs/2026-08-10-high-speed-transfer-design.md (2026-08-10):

# DayVault High-Speed Export - Design

Date: 2026-08-10
Status: Approved by user

## Goal

Reduce the time required to export a full day of recordings over the existing
USB-C connector while preserving reliable recording, resumable downloads, and
the board's recoverable DFU path.

The current measured USB-only rate is about 240 KiB/s. The practical target for
the existing STM32L452 USB Full Speed hardware is 800 KiB/s or better for a
large contiguous file, with correctness and safe recovery taking priority over
a benchmark-only peak.

## Non-negotiable safety constraints

- Never modify STM32 option bytes, especially `nBOOT1`, `nBOOT0`, or
  `nSWBOOT0`.
- Never write the option-byte address range at `0x1FFF7800`.
- Preserve the existing software DFU reset flag and jump to system memory at
  `0x1FFF0000`.
- Keep ST's USB VID `0x0483`.
- Before any physical flash, verify DFU with `dfu-util -l`; after flashing,
  verify normal boot and that DFU remains reachable.
- A failed or interrupted download must never damage the recording on the SD
  card.

## Current bottlenecks

1. The linker exposes only 64 KiB of the STM32L452's 128 KiB SRAM1 and leaves
   the separate 32 KiB SRAM2 unused. Large 16 KiB local arrays overlap the
   approximately 5.5 KiB remaining stack.
2. SD reads use CMD17 once per 512-byte sector and call
   `HAL_SPI_TransmitReceive` once per byte at 10 MHz.
3. USB CDC uses one active IN transfer and a 2 KiB queue. The measured USB-only
   path reaches about 240 KiB/s, far below the Full Speed bulk ceiling.
4. `DL2` has no offset resume, end-to-end checksum, or machine-readable final
   status. The PC deletes partial files after a retry.
5. The PC performs blocking reads and writes each received chunk directly to
   disk, with progress callbacks on every chunk.

## Architecture

### 1. Correct memory map and fixed transfer workspace

- Expose 128 KiB SRAM1 at `0x20000000` and 32 KiB SRAM2 at `0x10000000`.
- Add an explicit `.ram2` `NOLOAD` section.
- Allocate two aligned 16 KiB transfer buffers in SRAM2. No large transfer
  buffers may live on the stack.
- Keep ordinary globals, heap, and stack in SRAM1. Report SRAM1 and SRAM2 usage
  independently in the map file.

### 2. Layered performance measurements

Provide independent commands and parsers for:

- USB generator to host: no SD access.
- SD file read to memory: no USB payload.
- End-to-end file export: SD through USB to PC disk.

Every result includes bytes, elapsed milliseconds, and integer KiB/s. The host
test also validates a deterministic byte pattern or a final CRC32.

### 3. SD read path

- Keep command traffic byte-oriented, but receive payload blocks with one HAL
  buffer transaction instead of 512 one-byte calls.
- Use CMD18 for contiguous multi-sector reads and CMD12 to stop, with CMD17 as
  a compatibility fallback.
- Raise normal SPI clock from 10 MHz to 20 MHz first. A 40 MHz/high-speed mode
  is enabled only after card capability negotiation and repeated integrity
  tests.
- Feed the watchdog while waiting for tokens and during long transfers.
- Preserve the existing write path until the read optimization is verified.

### 4. Export protocol

Introduce a versioned binary export command while keeping legacy `DL2` during
migration. The new command accepts a filename and byte offset, aligns SD access
to sectors internally, streams from that offset, and finishes with a structured
status containing total size, bytes sent, and CRC32 for the transmitted range.

The PC keeps `<name>.part`, resumes from its current length, and atomically
renames it only after size and CRC verification. Protocol parsing is isolated
from serial I/O so it can be unit-tested without hardware.

### 5. USB transport

Optimization is staged so every step is measurable:

1. Remove avoidable CDC copies and enlarge producer blocks after memory safety
   is fixed.
2. Configure the USB FS bulk IN path for continuous queued transfers and, where
   supported by the STM32 USB device library, double-buffer its PMA endpoint.
3. If Windows CDC remains the limiting layer, add a vendor-specific WinUSB bulk
   interface with Microsoft OS descriptors. The command/control interface may
   remain CDC during migration.

The final transport must keep USB packets continuously queued; SD reads and USB
transmits alternate between the two SRAM2 buffers.

### 6. PC pipeline

- Read into reusable large buffers and batch disk writes.
- Throttle GUI progress events by time and percentage rather than per read.
- Preserve partial files on transient errors.
- Reconnect and resume automatically from the verified partial length.
- Use several asynchronous WinUSB reads when that backend is enabled.

## Verification

- Host protocol, resume, CRC, and failure handling have automated tests.
- Firmware builds with map-file assertions proving SRAM1 stack headroom and
  exact SRAM2 buffer placement.
- SD integrity is checked by repeated reads and CRC comparison before raising
  its clock.
- Physical benchmarks record USB-only, SD-only, and end-to-end rates using the
  same board and file.
- A final DFU recovery check is mandatory; no option-byte command appears in
  source, scripts, or logs.

## Expected result

For a 3.64 GB day, 800 KiB/s reduces export to roughly 74 minutes; 1.0 MB/s is
roughly 61 minutes. The exact result depends on the SD card and Windows host,
but the design removes the current software bottlenecks without requiring a
PCB revision.

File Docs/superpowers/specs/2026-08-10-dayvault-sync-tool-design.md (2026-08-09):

# DayVault PC Sync Tool — Design

Date: 2026-08-10
Status: Approved by user

## Goal

A Windows desktop application (EXE) that:
- Detects DayVault recorder boards automatically when plugged in (USB CDC, VID 0483 / PID 5740).
- Auto-syncs each device's clock (time + timezone offset) on connect.
- Auto-downloads all not-yet-synced audio files from each device into a user-configured folder.
- Runs resident in the system tray; closing the window hides to tray, background detection continues, and only an explicit tray "Exit" terminates the program.

## Background / constraints

- Device USB identity: `USB\VID_0483&PID_5740\<serial>` where `<serial>` (e.g. `206C36943831`) is unique per MCU — the per-device key.
- Firmware serial protocol (COM9 @115200): `SETTIME <unix> [tz_minutes]` (overwrites stored tz offset), `LIST` (list root, `  <name> <size>` lines), `DL2 <file>` (chunked ACK download, preferred; prints `DLSTART <size>` then binary data; the host sends a single ACK byte, e.g. `G`, whenever no data has arrived for ~60 ms to prompt the next chunk — same behavior as the existing `download2.ps1`).
- Recordings are named `REC-YYYYMMDD-HHMM[_n][_dur].WAV` (local time) or legacy `REC###.WAV`; durations like `_5m32s` / `_1h23m45s`.
- Python 3.14 + pySerial 3.5 available on the dev machine.
- The device may be mid-recording while connected (USB attached → awake; LIST/DL2 no longer freeze recording after the firmware no-re-mount fix).

## Design

### 1. Architecture & tech stack

- **PySide6 (Qt)** GUI + **pySerial** serial + **PyInstaller** single EXE (`--windowed --onefile`).
- Threading: GUI on the main thread; all serial I/O (LIST, DL2, SETTIME) runs in a per-device worker `QThread` that emits signals (device list update, file list, download progress, errors) back to the UI. Never block the UI thread.
- Device detection: a `QTimer` (~1.5 s) polls `pyserial.tools.list_ports`, filters COM ports whose `VID:PID` is `0483:5740` (from the PNP `USB\VID_0483&PID_5740\`), diffs against the previous set → connect/disconnect events.
- Device key = the USB serial from the PNP id (e.g. `206C36943831`).

### 2. Auto-sync & download flow (per device, on connect)

Per-device worker, serialized per device, devices in parallel:
1. **Sync clock**: `SETTIME <now_unix> <local_tz_offset_minutes>` (offset = `datetime.now().utcoffset()` in minutes; overwrites stored offset on every sync).
2. **List**: `LIST` → parse `  <name> <size>` lines into a file list.
3. **Diff**: load the device's state file `{name: size}`; "to download" = listed files not in state, or size changed.
4. **Download** each missing file via `DL2` to `<sync_folder>/<serial>/`, writing to `<name>.part` then rename on success; update the state file after each successful download.
5. **Failures**: unplug mid-download → mark failed, retry on next insert; COM busy → backoff retry; non-DayVault 0483:5740 device → LIST fails → mark unrecognized and skip.

### 3. Main window, tray, settings

- **Main window**:
  - Device selector (multiple boards: tab or combo, keyed by serial).
  - File table: name, size, time (from name), sync status ("已下载" / "未下载").
  - Settings area: sync folder path picker, poll interval, launch-on-startup (optional).
- **Tray**: window close hides to tray (background detection continues). Tray icon left-click opens the window; tray menu "打开主界面" / "退出". Only "退出" exits the process.
- **Persistence**:
  - Config: `%APPDATA%/DayVault/config.json` (sync folder, poll interval, autostart).
  - Per-device state: `%APPDATA%/DayVault/state/<serial>.json` (`{name: size}`).
  - Logs: `%APPDATA%/DayVault/logs/app.log` (rotating).

### 4. Edge cases

- Recording in progress: a file without `_dur` suffix may still be growing; DL2 downloads the current bytes; a later size change re-downloads.
- Device asleep: USB attach wakes it; connected device is always awake.
- `.part` residue: cleaned on next download attempt.
- Two boards recording the same minute: per-device folders avoid collisions.

### 5. Testing & packaging

- Unit tests (host-side, no device): filename/`LIST` parsing, state-file load/save, tz offset computation.
- Integration (physical device): plug → auto time/tz sync → auto download of unsynced files to `<folder>/<serial>/` → UI shows 已下载/未下载; window close → tray resident; tray click reopens; tray Exit really exits; unplug/plug behavior.
- Packaging: PyInstaller build command; verify the single EXE runs.

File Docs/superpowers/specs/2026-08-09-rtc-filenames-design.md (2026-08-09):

# RTC Timestamped Recording Filenames — Design

Date: 2026-08-09
Status: Approved by user

## Goal

Replace the current sequence-based recording filenames (`REC%03u.WAV`, e.g. `REC062.WAV`)
with human-readable names that contain the **recording start time** (local, minute
precision) and the **recording duration**, e.g.:

- During recording: `REC-20260809-1110.WAV`
- After stop (renamed): `REC-20260809-1110_5m32s.WAV` (>=1 h uses `_1h23m45s`)

## Background / constraints

- The RTC runs on a 3.3 V rail with **no coin cell**. While powered (USB or battery,
  battery is permanently attached) the RTC keeps time across reset/flash/sleep. A fresh
  board or a fully-drained battery with USB unplugged resets the clock to the default
  2026-01-01 00:00 (`dt_init`).
- `SETTIME <unix>` sets the RTC from a UTC unix epoch. The RTC stores UTC civil time;
  a UTC offset is applied only at render time (filenames, INFO).
- FatFs LFN is configured in `lib/FatFs/ffconf.h` as `_USE_LFN 2` (`_MAX_LFN 255`,
  exFAT on), but the compiled `ff.c.o` references `ff_convert` yet **no `ff_memalloc`**,
  so the effective LFN configuration is uncertain and long names are NOT yet proven to
  work. This must be brought up and verified first (see LFN bring-up).

## Design

### 1. Filename scheme

- **Start (`rec_start`)**, when time is set (`time_set == 1`):
  - Build a local-time minute-precision name: `REC-YYYYMMDD-HHMM.WAV`
  - Open with `FA_CREATE_NEW`; on `FR_EXIST`, retry with suffix `_1` .. `_9`
    (e.g. `REC-20260809-1110_2.WAV`).
  - If the long-name open fails for any other reason, **fall back to the sequence
    naming** `REC%03u.WAV` (recording must never be blocked by naming).
- **Stop (`rec_stop`)**:
  - Duration = `rec_data_bytes / byte_rate`, where `byte_rate` is taken from the actual
    `rec_cfg` (channels * bytes-per-sample * sample rate; 16-bit mono 21000 Hz = 42000 B/s).
  - Render duration: `<h>h<mm>m<ss>s` for >=1 h, `<mm>m<ss>s` for <1 h.
  - `f_rename` to `REC-YYYYMMDD-HHMM[_n]_5m32s.WAV`. The creation suffix `_n` (if any)
    is preserved before the duration.
  - If `f_rename` fails, keep the start-time name (no data loss).
- **When time is not set** (`time_set == 0`): use the existing sequence naming
  (`REC%03u.WAV`). Timestamp-named files are skipped by `fs_next_sequence` naturally
  (`parse_num` stops at `-` and yields 0), so old `REC###` files and new timestamp
  files coexist.

### 2. Time sync & timezone

Backup domain additions (same mechanism as the existing BKP0R init magic; they reset
on power loss). Stored packed in a spare backup data register (e.g. `BKP1R`):
`time_set` flag + `tz_offset` (int32 minutes, default **+480**, UTC+8, current dev PC).
Applied only at render time; the RTC calendar itself stays UTC.

Commands:

- `SETTIME <unix> [tz_minutes]` — sets the RTC to UTC unix, sets `time_set`, and
  **if `tz_minutes` is given, overwrites the stored offset** (a PC sync always sends it,
  so each sync overwrites the old timezone). If omitted, the stored offset is kept.
- `SETTZ <minutes>` — set the UTC offset only (does not touch the clock).

Rendering:

- Filenames use local time (`dt_get_unix` + offset, then civil).
- `INFO` reports `time=` as local time and adds `tz=<offset_minutes>` and `time_set=1`.
- `REC started seq=` message additionally prints the actual filename.

### 3. LFN bring-up (mandatory first step)

- FatFs is **R0.12c**; the current config `_USE_LFN 2` means LFN with a **dynamic
  working buffer on the stack** (`WCHAR lbuf[_MAX_LFN+1]` local array; `ff_memalloc`
  only applies to `_USE_LFN 3`, so none needs to be implemented). Long names are
  therefore already supported by the config — verify empirically.
- Because `_MAX_LFN 255` + `_FS_EXFAT 1` puts ~1.1 KB on the stack per LFN operation
  (512 B `lbuf` + 608 B `dirbuf`), reduce `_MAX_LFN` to **40** (our longest generated
  name is ~31 chars) to cut that to ~242 B and keep stack headroom.
- Empirically verify on the SD card: create `REC-20260809-1110_5m32s.WAV`, see it in
  `f_readdir`, rename it with `f_rename`.

### 4. Affected existing code

| Location | Change |
|---|---|
| `main.cpp rec_start/rec_stop` | Timestamp name generation, duration math, `f_rename`, collision retry, seq fallback |
| `main.cpp check_wav_file` (CHECK cmd) | Find newest recording by lexicographically largest filename instead of `seq-1` |
| `DeviceTime` | Local-time formatting; backup-domain `time_set`/`tz_offset`; `SETTIME` offset arg; `SETTZ` |
| `INFO` | `time=` local, add `tz=` and `time_set=` |
| `REC started seq=` | Append actual filename |
| `LIST` / `fs_next_sequence` | No logic change expected (LFN `fname` is the long name; `parse_num` yields 0 for `REC-`) — verify in LFN bring-up |
| Docs `Serial-Command-Reference.md` | `SETTIME` new syntax, `SETTZ`, `INFO` new fields, recording naming behavior (timestamp+duration, collision suffix, unset fallback, RTC/timezone semantics) |

### 5. Power-loss / crash safety (recording must not corrupt or lose files)

Current gaps: `rec_start` writes the 44-byte header once with `data_size=0` and does not
`f_sync`; recording never `f_sync`s. On a power loss the header says 0 bytes and the FAT
directory size may still show ~44 bytes, so recorded data appears lost.

- **Start**: after writing the header, `f_sync` immediately so the header is durable even
  if power is lost very early (valid, empty WAV).
- **During recording (checkpointing)**: every ~1 s, rewrite the 44-byte header
  (`RIFF` size + `data_size = rec_data_bytes`) and `f_sync` (flush data + update FAT
  directory size). On power loss the file is playable up to the last sync (<= ~1 s of
  data + trailing <=64-byte chunk lost, bounded). Cost: one 512 B sector + directory
  write per second (negligible wear); the PDM ring buffer absorbs any SD stall, no
  audio dropout.
- **Low-battery sleep entry**: if recording, call `rec_stop()` first (clean finalize:
  rebuild header + sync + close) before entering STOP, so no file is left in a
  half-written state across sleep.
- **After a power loss**: the file keeps its start-time name (no duration suffix), but
  has a valid header, correct size, and is playable. The missing duration suffix is
  acceptable (only a clean stop renames to the duration form).

### 6. Affected existing code

| Location | Change |
|---|---|
| `main.cpp rec_start/rec_stop` | Timestamp name generation, duration math, `f_rename`, collision retry, seq fallback; header `f_sync` at start; periodic header-update + `f_sync` checkpointing |
| `main.cpp low_battery_enter_stop` / sleep entry | `rec_stop()` first if recording is active |
| `main.cpp check_wav_file` (CHECK cmd) | Find newest recording by lexicographically largest filename instead of `seq-1` |
| `DeviceTime` | Local-time formatting; backup-domain `time_set`/`tz_offset`; `SETTIME` offset arg; `SETTZ` |
| `INFO` | `time=` local, add `tz=` and `time_set=` |
| `REC started seq=` | Append actual filename |
| `LIST` / `fs_next_sequence` | No logic change expected (LFN `fname` is the long name; `parse_num` yields 0 for `REC-`) — verify in LFN bring-up |
| Docs `Serial-Command-Reference.md` | `SETTIME` new syntax, `SETTZ`, `INFO` new fields, recording naming behavior (timestamp+duration, collision suffix, unset fallback, power-loss/crash recovery, RTC/timezone semantics) |

### 7. Error handling

- Long-name open failure -> sequence-name fallback; recording continues.
- `f_rename` failure -> keep the start-time filename; file is intact.
- Header-update / `f_sync` failure during recording -> keep recording (best-effort
  checkpointing); the final `rec_stop` still attempts a clean finalize.
- No path may block or lose a recording.

### 8. Testing

1. LFN bring-up empirical test (create / readdir / rename on the SD card).
2. Build + flash.
3. `SETTIME <unix> 480` then `REC`/`STOP` — verify `REC-YYYYMMDD-HHMM.WAV` created and
   renamed to `REC-..._MmSs.WAV` on stop.
4. Two recordings in the same minute — verify `_1` suffix.
5. Power-loss drill: during recording, unplug USB and pull the battery (or kill power),
   re-power, and confirm the file is playable with data up to the last checkpoint and a
   valid header.
6. `INFO` shows local time + `tz=+480` + `time_set=1`.
7. `LIST` shows long names; `DOWNLOAD`/`DL2` still work by exact name.
8. Docs updated and reviewed.

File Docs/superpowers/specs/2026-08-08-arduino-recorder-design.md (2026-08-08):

# DayVault Arduino Recorder — Design

Date: 2026-08-08
Status: Approved by user (2026-08-08)
Scope: Switch the DayVault recorder firmware to the STM32duino (Arduino) platform and
implement the core use case: USB detach auto-starts mono recording; USB attach auto-stops
recording and re-enumerates as CDC+MSC so the 128 GB exFAT card can be exported on Windows.

## 1. Goals and Non-Goals

### Goals

- All project-owned firmware code is rewritten from scratch in an Arduino (STM32duino)
  project. No old HAL/Cube C files are reused as project code.
- USB detach -> automatically start recording.
- USB attach -> automatically stop recording, finalize the WAV file, and expose the SD
  card as a mass-storage device (MSC) so Windows shows it like an external drive.
- USB enumerates as CDC (serial) + MSC (disk) composite: serial for debug output and the
  `DFU` command, MSC for file export.
- Mono 16 kHz / 16-bit PCM WAV recording on Channel 1 (PB12/DFSDM1_DATIN1). Stereo is a
  later milestone.
- Recording files named `REC###.WAV`, one file per recording session, sequential numbers.
- exFAT 128 GB SDXC card supported (FatFs `_FS_EXFAT=1` already configured).
- Repo reorganization: old HAL/Cube firmware and firmware-related docs move to a
  `legacy/hal-firmware` git worktree; main keeps only what the new development needs.

### Non-Goals (later milestones)

- Stereo two-microphone capture (M3).
- RTC synchronization and date-based file names (current files are sequential).
- Battery ADC / low-battery handling.
- Power-fail file closure beyond f_sync/f_close.
- PDM gain calibration, IMA ADPCM or Opus.

## 2. Decisions (from brainstorming Q&A)

| Decision | Choice |
| --- | --- |
| Code rewrite scope | All project code rewritten; framework libraries (HAL, ST USB device library, FatFs) used as dependencies |
| Recording format | Mono first, stereo later (current milestone mono) |
| Audio spec | 16 kHz / 16-bit PCM WAV, `REC###.WAV` sequential, one file per session |
| USB device shape | CDC + MSC composite (serial for debug/DFU command, disk for export) |
| File naming | Sequential `REC###.WAV`, no fake date names (RTC unreliable) |
| DFU entry | BOOT button (hardware) + CDC `DFU\n` command (software jump); NO boot-time PH3 auto-trigger |
| LED feedback | PA8: slow blink while recording, solid while idle/MSC, fast blink on error |
| MSC write policy | Read-only export volume (matches prior firmware, safest) |

## 3. Repository Reorganization (worktree)

### Target layout

```
C:\Users\Administrator\Desktop\DayVault\            <- main (new Arduino development)
|-- AGENTS.md                 keep (HARD RULES)
|-- README.md / README.zh-CN.md
|-- EDA/                      keep (hardware unchanged)
|-- Docs/
|   |-- superpowers/          keep (specs/plans directory)
|   |-- 01-Hardware-Overview.md   keep
|   |-- 02-MCU-Pinout.md          keep (pin table for new firmware)
|   |-- 03-Component-Pinout.md    keep
|   |-- 07-BOM.md                 keep
|   `-- 08-Net-Map.md             keep (net -> endpoint map)
|-- firmware/                 rebuilt as Arduino project
|   |-- platformio.ini
|   |-- boards/               reuse board json + linker script
|   |-- lib/FatFs/            library dependency (exFAT enabled)
|   |-- src/                  all-new Arduino source
|   `-- test/                 host unit tests
|-- .github/ .gitignore .gitattributes .superpowers/

C:\Users\Administrator\Desktop\DayVault-legacy\     <- legacy/hal-firmware worktree
|-- firmware/                 old HAL/Cube firmware (src/, hw_*.c, arduino_test, ...)
|-- Docs/
|   |-- 00-开发速查.md            old firmware dev flow
|   |-- 05-Bringup-and-Test.md   old bring-up procedure
|   |-- 06-Known-Issues.md       old blocker register
|   |-- 09-USB-DFU-Entry-Design.md  old software-DFU design
|   `-- superpowers/plans,specs  old firmware design + implementation plan
|-- (everything else preserved as-is)
```

### Steps

1. `git worktree add` branch `legacy/hal-firmware` at sibling directory
   `DayVault-legacy`.
2. In main, `git rm` old firmware code and firmware-related docs, commit.
   Old content remains fully preserved on the `legacy/hal-firmware` branch.
3. Develop the new Arduino firmware in main.

## 4. Firmware Architecture

Module layout in `firmware/src/` (one clear responsibility per module):

| Module | Responsibility |
| --- | --- |
| `main.cpp` | `setup()`/`loop()`; clock config (80 MHz MSI->PLL, USB 48 MHz HSI48, Range 1 first); init; main scheduling |
| `Config.h` | Pin and constant definitions (PDM / SD / USB / LED / BOOT) |
| `Recorder.h/.cpp` | State machine IDLE -> RECORDING -> STOPPING -> MSC |
| `PdmCapture.h/.cpp` | DFSDM1 mono PDM capture: Channel 1 direct (DATIN1/PB12), SINC3, OSR 128, CKOUT 2.048 MHz, DMA half/complete interrupts -> ring buffer |
| `RingBuf.h/.cpp` | Lock-free-ish ring buffer (pure logic, host-testable) |
| `SdCard.h/.cpp` | SPI1 block device: CMD0/8/55/41 init, CSD read, single/multi-block read+write (PA4-7) |
| `diskio.c` | FatFs disk glue (SdCard <-> FatFs) |
| `WavFile.h/.cpp` | WAV header build + size patch (pure logic, host-testable) |
| `UsbComposite.h/.cpp` | CDC+MSC composite via the ST USB device library bundled in STM32duino; MSC storage callbacks read raw SD blocks (read-only) |
| `Dfu.h/.cpp` | Software jump to ROM bootloader (0x1FFF0000) with stack-pointer validation |
| `Cmd.h/.cpp` | Serial command parse: `DFU\n` -> enter DFU; `INFO\n` -> print status |

### Data flow (recording)

```
PDM mic (PB12) -> DFSDM1 Filter1 -> DMA half/full IRQ -> RingBuf
   -> loop() pump -> FatFs -> SD card REC###.WAV (exFAT)
```

### USB switch behavior

```
USB detach (PA9 debounced) -> open REC###.WAV + start capture -> RECORDING
USB attach (PA9 debounced) -> stop capture -> drain RingBuf -> patch WAV header
   -> f_sync + f_close -> f_unmount (FatFs flushed)
   -> start CDC+MSC composite USB (Windows: disk + serial)
USB detach again -> stop USB -> f_mount -> record next REC###.WAV
```

### Clocks

Reuse the clock tree already proven in `arduino_test`: MSI 8 MHz -> PLL (M=1,N=20,R=2) ->
80 MHz SYSCLK; USB FS 48 MHz from HSI48. L4 requires VOS Range 1 before 80 MHz.

### RAM budget (64 KB total)

DFSDM ring buffer starts at 16 KB (enough for DMA double-buffer + disk pump), FatFs +
USB stack + SD buffers ~20 KB, remainder for stack/heap. Measured on hardware; shrink ring
buffer if needed. Reference: old HAL firmware used 48 KB (73%), so this must be verified.

### LED (PA8)

Slow blink while recording; solid while idle/MSC; fast blink on error.

## 5. Error Handling

| Scenario | Handling |
| --- | --- |
| SD init/mount fails at boot | No recording; enter MSC state; LED fast blink; retry on next USB cycle |
| SD write failure during recording | Stop capture, patch header, close file, mark failed (file kept), LED error, recover on USB cycle |
| Ring buffer overflow | Count overruns (queryable via serial), drop frames, never crash |
| USB attach during power risk | Periodic f_sync keeps FatFs flushed; header patched at close |
| Software DFU jump | Validate bootloader stack pointer before jump; loop forever (no jump) if invalid |

## 6. Testing Strategy

### Host unit tests (`native` env, Unity)

- `RingBuf`: write/read, wraparound, full/empty, ISR atomicity.
- `WavFile`: header bytes golden test (16 kHz / 16-bit mono), size patch.
- `Recorder`: state machine transitions for USB attach/detach event sequences.
- `Cmd`: `DFU\n` and `DFU\r\n` produce the enter-DFU event; unknown lines do not.

### Board verification (DFU flash + serial + disk)

1. Power on, USB detached -> recording starts (LED slow blink).
2. Plug USB -> recording stops -> Windows shows exFAT 128 GB disk + serial port.
3. Open disk: REC001.WAV copies out and plays.
4. Serial `DFU\n` -> device re-enumerates as STM32 BOOTLOADER -> can re-flash.

### Milestones

- **M0** Repo reorganization (worktree) + Arduino project skeleton compiles.
- **M1** Mono PDM -> SD (exFAT) recording with USB auto start/stop (this milestone).
- **M2** USB CDC+MSC composite + export verification.
- **M3** Stereo, RTC/battery, and follow-ups.

## 7. Safety (AGENTS.md compliance)

- Never modify option bytes / boot-config bits; this design touches flash only for the
  application image via the ROM DFU path.
- Software DFU entry goes through the validated `dfu_enter`-style jump; the BOOT button
  remains the hardware recovery path.
- Confirm DFU availability (`dfu-util -l`) before every DFU flash and confirm normal
  reset after flashing.
- No boot-time PH3 auto-DFU trigger in the new firmware.

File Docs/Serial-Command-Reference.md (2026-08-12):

# DayVault Serial Command Reference

This is the USB CDC serial interface for the DayVault STM32L452 firmware and its audio export path.

## Connection

- USB CDC virtual serial port, **115200 baud**, 8N1.
- CDC enumerates as VID/PID `0483:5740`. During a `BULK2` export it temporarily re-enumerates as the WinUSB device `0483:5741`, then returns to CDC.
- Commands are case-sensitive ASCII lines ending in `\n` or `\r`.

## Recording behavior

With USB detached (PA9 low), the device starts recording automatically. With USB attached, it cleanly stops recording before serial use. `REC` and `STOP` provide the same manual control.

New recordings are standard Ogg Opus `.OPUS` files: adaptive dual-microphone fusion to mono, exact 16 kHz PCM input, 20 ms frames, and target 24 kbit/s constrained-VBR restricted SILK encoding. New production recordings do not create a WAV or PCM original. See [09-Opus-Recording.md](09-Opus-Recording.md) for storage, finalization, and recovery behavior.

Timestamped recordings start as `REC-YYYYMMDD-HHMM.OPUS`, for example `REC-20260811-1430.OPUS`. On clean stop the name gains the duration: `REC-20260811-1430_5m32s.OPUS` or `REC-20260811-1430_1h04m03s.OPUS`. A collision is inserted before the duration: `REC-20260811-1430_1.OPUS` becomes `REC-20260811-1430_1_5m32s.OPUS`. If time is not set, the fallback is `REC001.OPUS`.

Completed Ogg pages contain at most 50 packets, about one second of audio. Newly completed pages are checkpointed about once a second. A clean stop drains the pipeline and encoder lookahead, writes Ogg EOS, syncs, closes, then renames timestamped recordings. An abrupt loss preserves the last synced prefix but can lose the page in progress.

Legacy `.WAV` files are still listed, downloadable, and eligible for circular deletion. They are not produced by new recordings.

## Commands

| Command | Description | Example response |
| --- | --- | --- |
| `INFO` | Device, SD, local-time, battery, and timezone status. | `INFO ... free=119990MB time=2026-08-11 14:30:00 bat=3850mV pct=71 tz=480 time_set=1` |
| `SETTIME <unix> [tz_minutes]` | Set UTC RTC time; optional timezone offset is stored for local names and `INFO`. | `TIME set to 2026-08-11 14:30:00` |
| `SETTZ <minutes>` | Set the timezone offset only. | `TZ set to 480` |
| `TIME` | Raw RTC diagnostic. | `TR=... DR=...` |
| `REC` | Start manual Opus recording. | `REC started seq=0 name=0:/REC-20260811-1430.OPUS` |
| `STOP` | Cleanly finalize the current recording. | `AUTO stop err=ok bytes=... rate=16000` |
| `OPUSSTAT` | Print Opus, Ogg, DSP, DMA, and recorder statistics. | `OPUSSTAT bitrate=24000 rate=16000 ...` |
| `LIST` | List SD-root files and sizes, including `.OPUS` and legacy `.WAV`. | `REC001.OPUS 123456` |
| `CIRC` | Report free space and run one delete-oldest pass. | `CIRC free_before=... deleted=0 free_after=...` |
| `DELOLDEST` | Delete the oldest completed `.OPUS` or legacy `.WAV` recording. | `DELOLDEST deleted=1` |
| `DOWNLOAD <file>` | Raw legacy CDC download. | `DLSTART <size>` then `DLEND read=<n> wr=<n>` |
| `DL2 <file>` | Chunked ACK CDC download. | `DLSTART <size>` then `DLEND read=<n>` |
| `GET2 <offset> <file>` | Resumable CRC32-verified CDC export. | `GET2START ...` then `GET2END ...` |
| `BULK2 <offset> <file>` | Preferred resumable WinUSB export. | `BULK2READY ...` |
| `BULKSPEED` | Send a deterministic 2 MiB WinUSB benchmark. | `BENCH bulk ...` |
| `SPEED` / `SDSPEED` | Measure USB or SD throughput. | `BENCH usb ...` / `BENCH sd ...` |
| `DFU` | Enter the STM32 ROM DFU bootloader. | Device re-enumerates as DFU. |
| `MOUNT` / `SD` | SD mount or card-init diagnostics. | `MOUNT fr=0` / `SD init=OK ...` |
| `LTEST` | Long-filename diagnostic. | `LTEST mount=0 ...` |
| `CHECK`, `CAPT` | Legacy recording/capture diagnostics; not production Opus recording. | Diagnostic output. |
| `DBG`, `DMAT`, `DUAL`, `RAW`, `ITST`, `SAMP` | Firmware, DMA, microphone, and capture diagnostics. | Diagnostic output. |
| `MBR`, `WRITE`, `SDWRITE` | SD read/write diagnostics. | Diagnostic output. |
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

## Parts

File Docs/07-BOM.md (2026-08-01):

# Bill of Materials

Generated from `EDA/DayVault.netlist.json`, schematic component count: **50**. Values and
supplier codes below describe the saved design; availability, lifecycle, footprint, voltage
rating, and assembly suitability must be rechecked before ordering.

## Integrated circuits and functional parts

| Qty | References | Manufacturer part/value | LCSC code | Saved footprint | Function |
| ---: | --- | --- | --- | --- | --- |
| 2 | U1, U2 | SPH0655LM4H-1-8 | C22376158 | MIC-SMD_SPH0655LM4H-1-8 | 1.8 V PDM microphones. |
| 1 | U3 | MCP73831T-2ACI/OT | C424093 | SOT-23-5 | 1-cell Li-ion charger. |
| 1 | U4 | XC6206P182MR | C21659 | SOT-23-3 | Fixed 1.8 V LDO. |
| 1 | U5 | STM32L452RCT6 | C192722 | LQFP-64, 0.5 mm pitch | Main MCU. |
| 1 | U6 | TPS63031DSKR | C15516 | SON-10 with exposed pad | Fixed 3.3 V buck-boost. |
| 1 | U7 | TXU0202DCUR | C5186957 | VSSOP-8 | Dual fixed-direction level translator. |
| 1 | D1 | USBLC6-2SC6 | C7519 | SOT-23-6 | USB D+/D- ESD protection. |
| 1 | L1 | SWPA3015S1R5NT, 1.5 uH | C56594 | 3.0 x 3.0 mm inductor | TPS63031 power inductor. |
| 1 | X1 | CM8V-T1A-32.768KHZ-7PF-20PPM-TA-QC | C5136974 | 2.0 x 1.2 mm crystal | 32.768 kHz RTC crystal, 7 pF. |
| 1 | CARD1 | TF-01A | C91145 | TF-SMD_TF-01A | microSD socket. |
| 1 | USB1 | TYPE-C 16PIN 2MD(073) | C2765186 | USB-C-SMD_TYPE-C-16PIN-2MD-073 | USB 2.0 Type-C receptacle. |
| 2 | SW1, SW2 | TS-1088-AR02016 | C720477 | 3.9 x 3.0 mm SMD switch | RESET and BOOT buttons. |

## Resistors

All saved resistor footprints are 0603. Use at least 1% parts unless a later calculation
specifies tighter tolerance.

| Qty | References | Value | Purpose |
| ---: | --- | ---: | --- |
| 2 | R1, R2 | 5.1 kOhm | USB Type-C CC1/CC2 Rd pull-downs. |
| 4 | R3, R4, R5, R6 | 10 kOhm | BOOT0 pull-down, NRST pull-up, charger current programming, SD_CS pull-up. |
| 2 | R7, R8 | 1 MOhm | Battery ADC divider. |
| 2 | R9, R10 | 100 kOhm | USB VBUS detect divider; schematic-only until PCB synchronization. |

## Capacitors

All saved capacitor footprints are 0603.

| Qty | References | Value | Main use |
| ---: | --- | ---: | --- |
| 15 | C1, C5-C12, C15, C19-C23 | 100 nF | Local decoupling, reset RC, battery sense filter. |
| 1 | C26 | 10 nF | USB insertion-detect filter; schematic-only until PCB synchronization. |
| 4 | C2, C3, C4, C16 | 10 uF | Converter input/output and microSD bulk decoupling. |
| 2 | C13, C14 | 4.7 uF | Charger input and battery output capacitors. |
| 2 | C17, C18 | 1 uF | 1.8 V LDO input and output capacitors. |
| 2 | C24, C25 | 10 pF | RTC crystal load capacitors. |

Selection requirements:

- Use C0G/NP0 dielectric for C24 and C25.
- Use X7R/X5R for rail capacitors and account for DC-bias loss, especially 10 uF in 0603.
- USB_5V and BAT capacitors should have comfortable voltage margin; 10 V-rated parts are a
  practical starting point, subject to exact vendor curves.
- Confirm the TPS63031 input/output effective capacitance and ESR against its datasheet.
- Place every 100 nF decoupler at its assigned IC supply pin, not merely anywhere on the net.

## Off-board items

| Qty | Item | Requirement |
| ---: | --- | --- |
| 1 | Li-polymer battery | Intended 802525, 3.7 V, 400 mAh, with protection board and correctly polarized leads. |
| 1 | microSD card | High-endurance, capacity selected from final codec and retention target. |
| 1 | USB-C cable | USB 2.0 data-capable cable, not charge-only. |
| 1 | Battery wire strain relief | Mechanical retention so solder joints cannot carry pull force. |

## BOM validation before purchase

- Confirm every exact LCSC code is stocked and eligible for the intended JLCPCB assembly
  service tier.
- Verify symbol pin numbers against the manufacturer datasheet, not only the marketplace
  listing.
- Verify footprint dimensions, pin-1 orientation, exposed pad, acoustic port, connector
  shell, and microSD card insertion direction with a 1:1 print.
- Confirm L1 saturation current and DCR for worst-case converter load.
- Confirm the selected 400 mAh cell permits the programmed approximately 100 mA charge rate.
- Freeze passive manufacturer parts and voltage/tolerance/dielectric fields before production.
- Regenerate this table after any future schematic/PCB change and reconcile the remaining
  DRC-reported netlist mismatch before manufacturing release.

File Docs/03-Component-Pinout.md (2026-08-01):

# Peripheral Components and Net Relationships

This document records the saved schematic connection of every functional component.
Reference designators match the EasyEDA project and exported netlist.

## U1 and U2: SPH0655LM4H-1-8 PDM microphones

| Pin | Name | U1 connection | U2 connection | Purpose |
| ---: | --- | --- | --- | --- |
| 1 | DATA | `PDM_DATA` | `PDM_DATA` | Shared, tri-stated PDM data line. |
| 2 | SELECT | `GND` | `1V8` | Selects opposite PDM clock edges for the two microphones. |
| 3 | GND | `GND` | `GND` | Ground. |
| 4 | CLOCK | `PDM_CLK` | `PDM_CLK` | Shared 1.8 V PDM clock. |
| 5 | VDD | `1V8` | `1V8` | Microphone supply. |

C20 decouples U1 VDD and C19 decouples U2 VDD; both are 100 nF to GND. Place each
capacitor beside its microphone supply pin. The bottom acoustic port must align with a
PCB hole and enclosure sound channel, with no copper, mask, adhesive, or contamination
blocking it.

## U7: TXU0202DCUR level translator

| Pin | Name | Net | Function |
| ---: | --- | --- | --- |
| 1 | B2 | `PDM_CLK_3V3` | 3.3 V clock input from MCU. |
| 2 | GND | `GND` | Ground. |
| 3 | VCCA | `1V8` | A-side supply. |
| 4 | A2Y | `PDM_CLK` | 1.8 V clock output to microphones. |
| 5 | A1 | `PDM_DATA` | 1.8 V microphone data input. |
| 6 | OE | `1V8` | Translator always enabled while the 1.8 V rail exists. |
| 7 | VCCB | `3V3` | B-side supply. |
| 8 | B1Y | `PDM_DATA_3V3` | 3.3 V data output to MCU. |

C21 is 100 nF from VCCA to GND; C22 is 100 nF from VCCB to GND. The component implements
the required fixed directions: MCU clock B-to-A and microphone data A-to-B.

## U5: STM32L452RCT6

See [02-MCU-Pinout.md](02-MCU-Pinout.md) for the complete 64-pin table. Supply grouping:

- Pins 19, 32, and 64 VDD connect to `3V3`.
- Pins 18, 31, 47, and 63 VSS connect to `GND`.
- Pin 13 VDDA/VREF+ connects to `3V3`; pin 12 VSSA/VREF- connects to `GND`.
- Pin 48 VDDUSB connects to `3V3`, not USB VBUS.
- Pin 1 VBAT connects to `3V3` and powers the RTC backup domain while 3.3 V is present.

Local 100 nF capacitors C6, C8, C9, C10, C11, and C12 are present on 3.3 V/GND in the
saved design. During PCB review, assign one directly to each VDD/VDDA/VDDUSB supply point
and keep the loop short; do not group all decouplers in one physical location.

## U6: TPS63031DSKR 3.3 V buck-boost converter

| Pin | Name | Net | Function |
| ---: | --- | --- | --- |
| 1 | VOUT | `3V3` | Regulated output. |
| 2 | L2 | internal switch node `$1N11` | One side of L1. |
| 3 | PGND | `GND` | Power ground. |
| 4 | L1 | internal switch node `$1N14` | Other side of L1. |
| 5 | VIN | `BAT` | Power input. |
| 6 | EN | `BAT` | Always enabled whenever the battery is connected. |
| 7 | PS/SYNC | `GND` | Power-save operating selection. |
| 8 | VINA | `BAT` | Analog/input supply. |
| 9 | GND | `GND` | Signal ground. |
| 10 | FB | `3V3` | Output feedback/sense. |
| 11 | EP | `GND` | Exposed pad; solder to ground. |

L1 is 1.5 uH. C1 100 nF and C2 10 uF are input capacitors. C3 and C4 are 10 uF output
capacitors and C5 is 100 nF output bypass. These values and the chosen inductor must be
validated against the exact TPS63031 datasheet recommendations and component saturation
current before manufacture. Keep both switch-node loops extremely compact.

## U4: XC6206P182MR 1.8 V LDO

| Pin | Name | Net |
| ---: | --- | --- |
| 1 | GND | `GND` |
| 2 | VOUT | `1V8` |
| 3 | VIN | `3V3` |

C17 is 1 uF from input to GND and C18 is 1 uF from output to GND. The LDO has no enable
pin, so 1.8 V remains powered whenever 3.3 V is present.

## U3: MCP73831T-2ACI/OT Li-ion charger

| Pin | Name | Net | Function |
| ---: | --- | --- | --- |
| 1 | STAT | NC | Open-drain charge status is not used. |
| 2 | VSS | `GND` | Ground. |
| 3 | VBAT | `BAT` | Battery charge output. |
| 4 | VDD | `USB_5V` | 5 V charging input. |
| 5 | PROG | R5 to `GND` | Charge-current program. |

R5 is 10 kOhm, giving approximately 100 mA nominal charge current. C13 is 4.7 uF from
USB_5V to GND and C14 is 4.7 uF from BAT to GND. Only use a protected, single-cell Li-ion
or Li-polymer battery. There is no charger power-path/load-sharing controller.

## CARD1: TF-01A microSD socket

| Pin | Card signal | Net |
| ---: | --- | --- |
| 1 | DAT2 | NC |
| 2 | DAT3/CS | `SD_CS` |
| 3 | CMD/DI | `SD_MOSI` |
| 4 | VDD | `3V3` |
| 5 | CLK/SCLK | `SD_SCK` |
| 6 | VSS | `GND` |
| 7 | DAT0/DO | `SD_MISO` |
| 8 | DAT1 | NC |
| 9 | CD | NC |
| 10, 11, 12, 13 | shell/GND | `GND` |

R6 is a 10 kOhm pull-up from SD_CS to 3.3 V. C15 100 nF and C16 10 uF decouple the card.
Card detect is intentionally unused; firmware determines availability from card command
responses.

## USB1: USB Type-C receptacle, USB 2.0 device

| Connector pins | Net | Purpose |
| --- | --- | --- |
| A1/B12 and B1/A12 | `GND` | USB ground. |
| A4/B9 and B4/A9 | `USB_5V` | VBUS input. |
| A5 CC1 | R2 5.1 kOhm to GND | Device/sink Rd. |
| B5 CC2 | R1 5.1 kOhm to GND | Device/sink Rd. |
| A6 and B6 | `USB_DP_CONN` | D+ before ESD array. |
| A7 and B7 | `USB_DM_CONN` | D- before ESD array. |
| A8 and B8 | NC | SBU signals unused. |
| EH pins 13 and 14 | `GND` | Connector shield/hold-down tabs. |

Both same-polarity data contacts are joined so either plug orientation works. This is a
USB 2.0 peripheral/sink implementation; it is not USB host or USB Power Delivery.

## D1: USBLC6-2SC6 USB ESD protector

| Pin | Net |
| ---: | --- |
| 1 | `USB_DM_CONN` |
| 2 | `GND` |
| 3 | `USB_DP_CONN` |
| 4 | `USB_DP` |
| 5 | `USB_5V` |
| 6 | `USB_DM` |

Place D1 immediately behind the connector. Route connector data into pins 1/3 and leave
through pins 6/4 toward the MCU, without stubs. Pin 2 needs a very short ground path.

## X1: 32.768 kHz RTC crystal

- X1 pin 1 connects to PC15/OSC32_OUT and C24 10 pF to GND.
- X1 pin 2 connects to PC14/OSC32_IN and C25 10 pF to GND.
- The crystal is marked 7 pF load capacitance in the project.

Keep X1 and both load capacitors beside the MCU. Route no clocks, USB, SD, PDM, or switch
nodes beneath or near this loop. Do not place a ground trace between the two crystal pins.

## Reset and ROM boot controls

- R4 10 kOhm pulls NRST to 3.3 V; C7 100 nF connects NRST to GND; SW1 pulls NRST to GND.
- R3 10 kOhm pulls BOOT0 to GND; SW2 connects BOOT0 to 3.3 V while pressed.
- Normal boot: release both buttons and reset/power the board.
- ROM USB DFU: hold BOOT, press RESET, release RESET, then release BOOT.

## Battery sensing and USB detection

Battery measurement:

- R7 1 MOhm: `BAT` to `BAT_SENSE`.
- R8 1 MOhm: `BAT_SENSE` to GND.
- C23 100 nF: `BAT_SENSE` to GND.
- `BAT_SENSE` connects to PA0.

USB insertion measurement:

- R9 100 kOhm: `USB_5V` to `USB_DETECT`.
- R10 100 kOhm: `USB_DETECT` to GND.
- C26 10 nF: `USB_DETECT` to GND.
- `USB_DETECT` connects to PA9.

## Battery connection pads

The PCB uses two large free through-hole pads rather than a connector:

| Pad | Net | Approximate finished geometry |
| --- | --- | --- |
| 1 | `BAT` | 1.8 mm copper diameter, 0.8 mm drill |
| 2 | `GND` | 1.8 mm copper diameter, 0.8 mm drill |

Mark polarity clearly on silkscreen and add mechanical strain relief for battery wires.
The intended battery must include its own protection board.

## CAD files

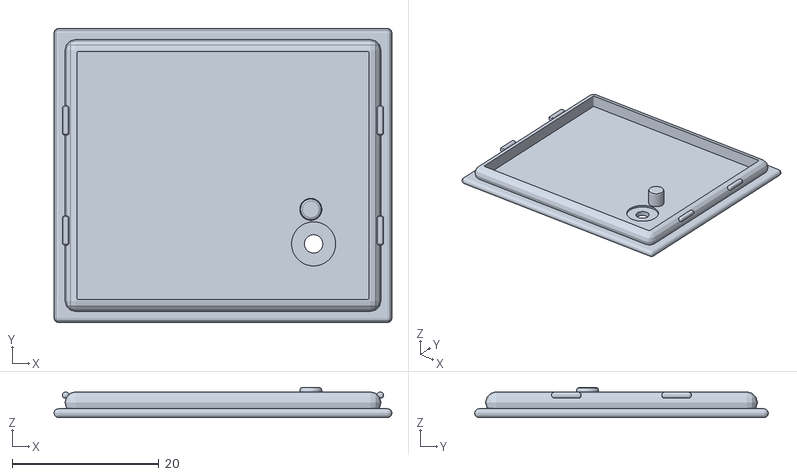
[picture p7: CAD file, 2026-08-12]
Mechanical/exports/DayVault_FrontCover.stl
46.0 x 40.0 x 4.10

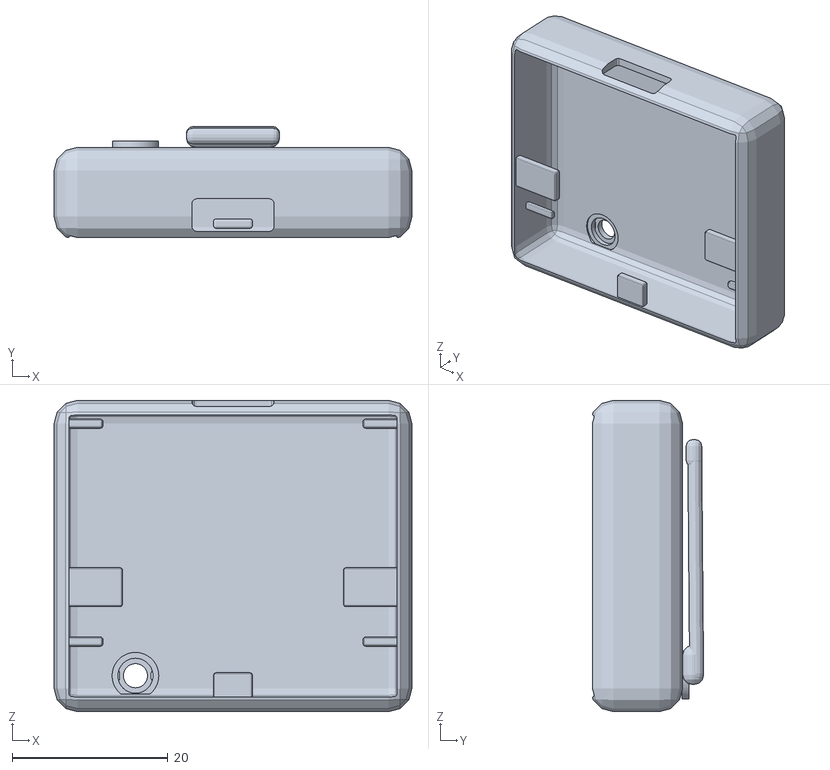
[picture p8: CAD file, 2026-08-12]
Mechanical/exports/DayVault_RearShell_Clip.stl
46.0 x 14.3 x 40.0

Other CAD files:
Mechanical/DayVault_Enclosure.blend

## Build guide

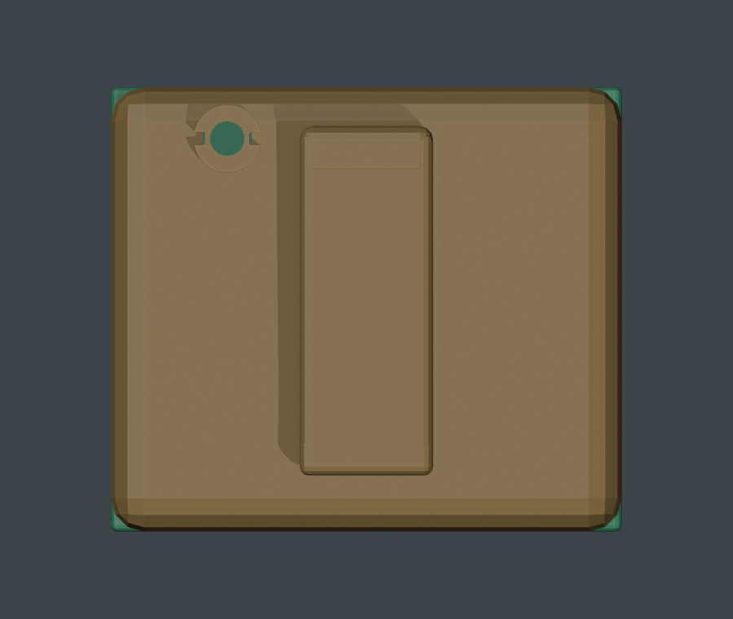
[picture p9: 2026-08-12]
Mechanical/exports/assembly_rear.png

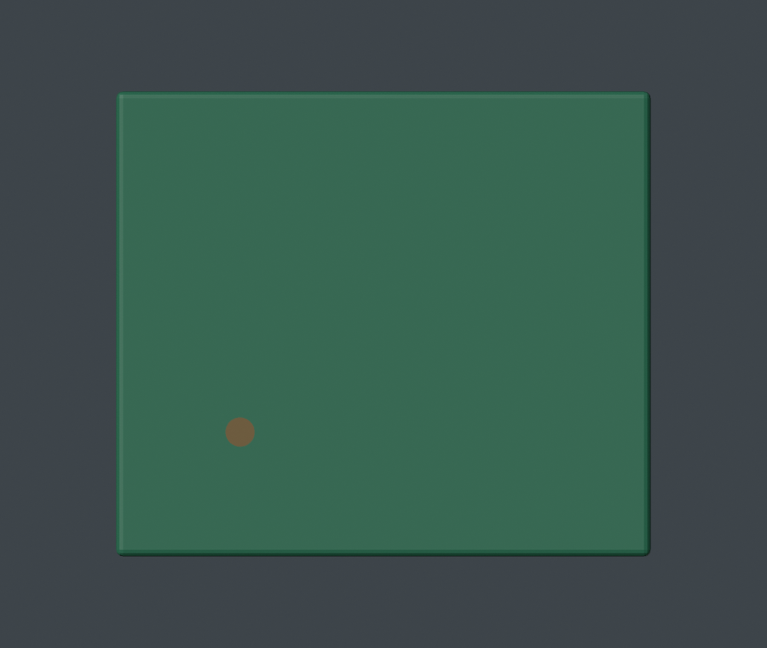
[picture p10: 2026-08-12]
Mechanical/exports/assembly_front.png

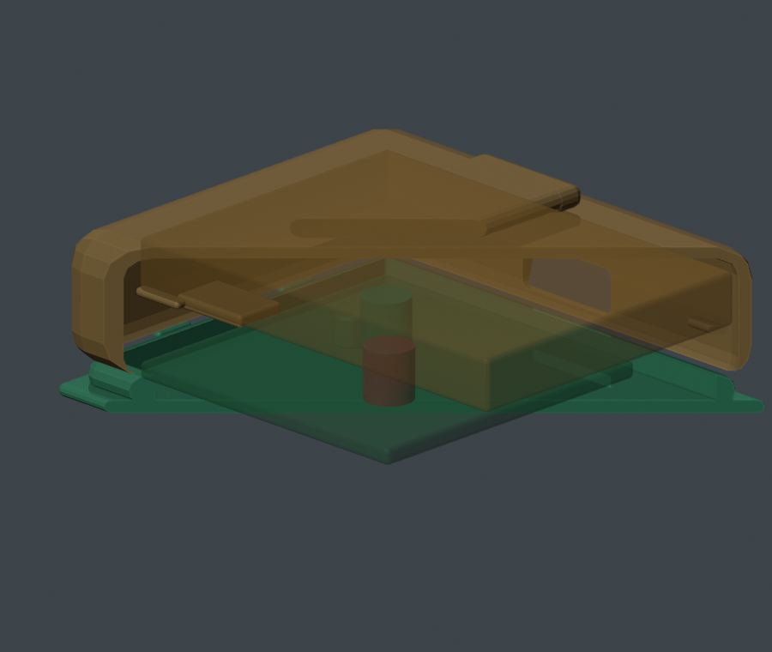
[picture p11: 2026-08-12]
Mechanical/exports/assembly_section.png

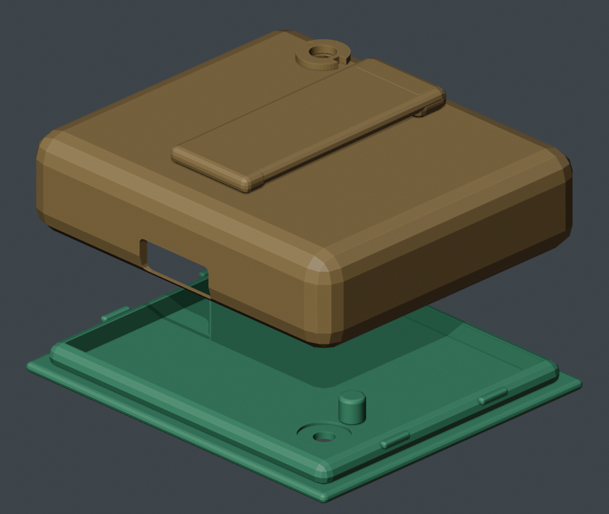
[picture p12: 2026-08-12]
Mechanical/exports/assembly_exploded.png

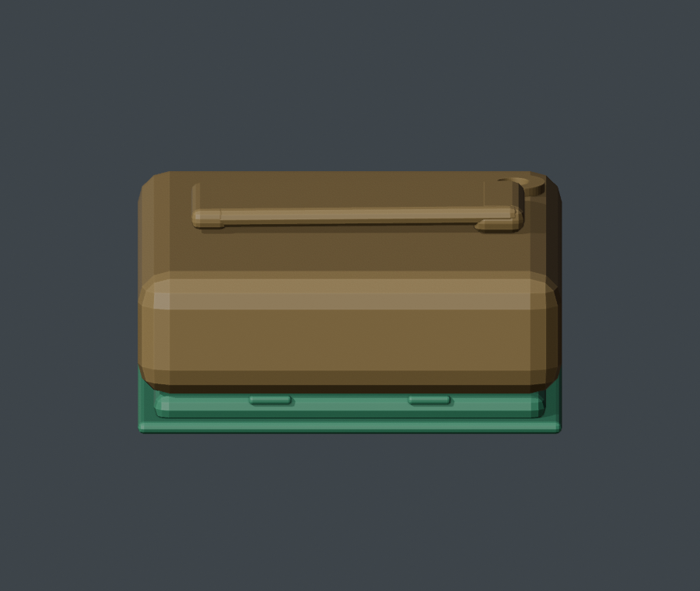
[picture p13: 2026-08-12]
Mechanical/exports/assembly_side.png

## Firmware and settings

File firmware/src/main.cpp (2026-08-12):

#include <Arduino.h>
#include "stm32l4xx_hal.h"
#include "Config.h"
#include "SdCard.h"
#include "Fs.h"
#include "ff.h"
#include "RingBuf.h"
#include "PdmCapture.h"
#include "WavFile.h"
#include "DeviceTime.h"
#include "Battery.h"
#include "TransferBuffer.h"
#include "Crc32.h"
#include "ExportProtocol.h"
#include "WinUsbDevice.h"
#include "CompressedRecorder.h"
#include <string.h>

extern "C" void SystemClock_Config(void);
extern "C" void CDC_init(void);
extern "C" void CDC_deInit(void);

void SystemClock_Config(void)
{
    RCC_OscInitTypeDef RCC_OscInitStruct = {0};
    RCC_ClkInitTypeDef RCC_ClkInitStruct = {0};
    RCC_PeriphCLKInitTypeDef PeriphClkInit = {0};

    if (HAL_PWREx_ControlVoltageScaling(PWR_REGULATOR_VOLTAGE_SCALE1) != HAL_OK) {
        while (1) { }
    }

    RCC_OscInitStruct.OscillatorType = RCC_OSCILLATORTYPE_MSI | RCC_OSCILLATORTYPE_HSI48;
    RCC_OscInitStruct.MSIState = RCC_MSI_ON;
    RCC_OscInitStruct.MSICalibrationValue = 0;
    RCC_OscInitStruct.MSIClockRange = RCC_MSIRANGE_7;
    RCC_OscInitStruct.HSI48State = RCC_HSI48_ON;
    RCC_OscInitStruct.PLL.PLLState = RCC_PLL_ON;
    RCC_OscInitStruct.PLL.PLLSource = RCC_PLLSOURCE_MSI;
    RCC_OscInitStruct.PLL.PLLM = 1;
    RCC_OscInitStruct.PLL.PLLN = 20;
    RCC_OscInitStruct.PLL.PLLP = RCC_PLLP_DIV7;
    RCC_OscInitStruct.PLL.PLLQ = RCC_PLLQ_DIV4;
    RCC_OscInitStruct.PLL.PLLR = RCC_PLLR_DIV2;
    if (HAL_RCC_OscConfig(&RCC_OscInitStruct) != HAL_OK) { while (1) { } }

    RCC_ClkInitStruct.ClockType = RCC_CLOCKTYPE_SYSCLK | RCC_CLOCKTYPE_HCLK |
                                  RCC_CLOCKTYPE_PCLK1 | RCC_CLOCKTYPE_PCLK2;
    RCC_ClkInitStruct.SYSCLKSource = RCC_SYSCLKSOURCE_PLLCLK;
    RCC_ClkInitStruct.AHBCLKDivider = RCC_SYSCLK_DIV1;
    RCC_ClkInitStruct.APB1CLKDivider = RCC_HCLK_DIV1;
    RCC_ClkInitStruct.APB2CLKDivider = RCC_HCLK_DIV1;
    if (HAL_RCC_ClockConfig(&RCC_ClkInitStruct, FLASH_LATENCY_4) != HAL_OK) { while (1) { } }

    PeriphClkInit.PeriphClockSelection = RCC_PERIPHCLK_USB;
    PeriphClkInit.UsbClockSelection = RCC_USBCLKSOURCE_HSI48;
    if (HAL_RCCEx_PeriphCLKConfig(&PeriphClkInit) != HAL_OK) { while (1) { } }
}

#define PIN_USB_DETECT 9    /* PA9 */
#define PIN_BOOT0       51  /* PH3 */

#define SYSTEM_MEMORY_BASE 0x1FFF0000u

volatile uint32_t g_dbg_step __attribute__((section(".noinit")));
volatile uint32_t g_dfu_jump __attribute__((section(".noinit")));
volatile uint32_t g_fault_pc __attribute__((section(".noinit")));
volatile uint32_t g_fault_lr __attribute__((section(".noinit")));
volatile uint32_t g_fault_step __attribute__((section(".noinit")));
volatile uint32_t g_fault_cfsr __attribute__((section(".noinit")));
volatile uint32_t g_fault_bfar __attribute__((section(".noinit")));
volatile uint32_t g_fault_mfar __attribute__((section(".noinit")));
volatile uint32_t g_fault_hfsr __attribute__((section(".noinit")));

static void dbg_step_set(uint32_t v) { g_dbg_step = v; }

extern "C" void HardFault_Handler(void)
{
    uint32_t sp = __get_MSP();
    g_fault_pc = *(volatile uint32_t*)(sp + 24u);
    g_fault_lr = *(volatile uint32_t*)(sp + 20u);
    g_fault_step = g_dbg_step;
    g_fault_cfsr = *(volatile uint32_t*)0xE000ED28u;
    g_fault_bfar = *(volatile uint32_t*)0xE000ED38u;
    g_fault_mfar = *(volatile uint32_t*)0xE000ED34u;
    g_fault_hfsr = *(volatile uint32_t*)0xE000ED2Cu;
    g_dbg_step = 0xDDDDDDDDu;
    NVIC_SystemReset();
    while (1) { }
}

static void dbg_iwdg_init(void)
{
    if ((RCC->CSR & RCC_CSR_LSION) == 0) RCC->CSR |= RCC_CSR_LSION;
    uint32_t t0 = HAL_GetTick();
    while ((RCC->CSR & RCC_CSR_LSIRDY) == 0 && (HAL_GetTick() - t0) < 50) { }
    IWDG->KR = 0x5555;
    IWDG->PR = 6;             /* /256 -> 125 Hz at 32 kHz LSI */
    IWDG->RLR = 4095;         /* maximum timeout; LSI tolerance still requires margin */
    IWDG->KR = 0xCCCC;
    IWDG->KR = 0xAAAA;
}

static void dbg_iwdg_kick(void) { IWDG->KR = 0xAAAA; }

static void dbg_report_last_step(void)
{
    uint32_t step = g_dbg_step;
    uint32_t csr = RCC->CSR;
    if (step == 0xDDDDDDDDu) {
        Serial.print("DBG previous=FAULT");
    } else if (step != 0) {
        Serial.print("DBG previous=step"); Serial.print(step);
    } else {
        Serial.print("DBG previous=clean");
    }
    Serial.print(" csr="); Serial.print(csr, HEX);
    RCC->CSR |= RCC_CSR_RMVF;
    Serial.println();
}

static uint8_t audio_buf[PDM_RING_BYTES];
static RingBuf audio_rb;
static bool transfer_workspace_busy = false;

static void print_benchmark(const char* layer, uint32_t byte_count,
                            uint32_t duration_ms, uint32_t crc32)
{
    if (duration_ms == 0) duration_ms = 1;
    const uint32_t kib_per_second = (uint32_t)(
        ((uint64_t)byte_count * 1000u) / ((uint64_t)duration_ms * 1024u));
    char crc_text[9];
    snprintf(crc_text, sizeof(crc_text), "%08lX", (unsigned long)crc32);
    Serial.print("BENCH "); Serial.print(layer);
    Serial.print(" bytes="); Serial.print(byte_count);
    Serial.print(" ms="); Serial.print(duration_ms);
    Serial.print(" kib_s="); Serial.print(kib_per_second);
    Serial.print(" crc32="); Serial.println(crc_text);
}

static int rec_name_cmp(const char* a, const char* b);

static void check_wav_file(void)
{
    DIR dir;
    FILINFO fno;
    char best[40];
    best[0] = 0;
    Serial.print("CHECK mount="); Serial.println(fs_mount_result());
    if (f_opendir(&dir, "0:/") == FR_OK) {
        while (f_readdir(&dir, &fno) == FR_OK && fno.fname[0]) {
            if ((fno.fattrib & AM_DIR) != 0) continue;
            if (strncmp(fno.fname, REC_DIR_STR, strlen(REC_DIR_STR)) != 0) continue;
            char* dot = strrchr(fno.fname, '.');
            if (dot == NULL || strcmp(dot + 1, "WAV") != 0) continue;
            if (best[0] == 0 || rec_name_cmp(fno.fname, best) > 0) {
                strncpy(best, fno.fname, sizeof(best) - 1);
                best[sizeof(best) - 1] = 0;
            }
        }
        f_closedir(&dir);
    }
    if (best[0] == 0) { Serial.println("CHECK none"); return; }

    FIL f;
    uint8_t hdr[44];
    UINT rd = 0;
    char name[44];
    snprintf(name, sizeof(name), "0:/%s", best);
    Serial.print("CHECK file="); Serial.println(name);
    if (f_open(&f, name, FA_READ) != FR_OK) { Serial.println("CHECK open FAIL"); return; }
    FRESULT r = f_read(&f, hdr, 44, &rd);
    Serial.print("CHECK hdr_fr="); Serial.print((int)r);
    Serial.print(" rd="); Serial.print(rd);
    if (rd == 44) {
        bool riff = (hdr[0]=='R'&&hdr[1]=='I'&&hdr[2]=='F'&&hdr[3]=='F'&&hdr[8]=='W'&&hdr[9]=='A'&&hdr[10]=='V'&&hdr[11]=='E');
        uint32_t data_sz = (uint32_t)hdr[40] | ((uint32_t)hdr[41]<<8) | ((uint32_t)hdr[42]<<16) | ((uint32_t)hdr[43]<<24);
        uint16_t ch = (uint16_t)(hdr[22] | (hdr[23]<<8));
        uint32_t rate = (uint32_t)hdr[24] | ((uint32_t)hdr[25]<<8) | ((uint32_t)hdr[26]<<16) | ((uint32_t)hdr[27]<<24);
        uint32_t bytes = (uint32_t)hdr[4] | ((uint32_t)hdr[5]<<8) | ((uint32_t)hdr[6]<<16) | ((uint32_t)hdr[7]<<24);
        Serial.print(" riff="); Serial.print(riff ? 1 : 0);
        Serial.print(" ch="); Serial.print(ch);
        Serial.print(" rate="); Serial.print(rate);
        Serial.print(" data="); Serial.print(data_sz);
        Serial.print(" riff_sz="); Serial.print(bytes);
        Serial.println();
    }
    f_close(&f);
}

static void lfn_bringup_test(void)
{
    FIL f;
    DIR dir;
    FILINFO fno;
    UINT wr = 0;
    const char* n1 = "0:/LTEST-20260809-1110_5m32s.WAV";
    const char* n2 = "0:/LTEST-20260809-1110_5m33s.WAV";
    Serial.print("LTEST mount="); Serial.println(fs_mount_result());
    FRESULT r = f_open(&f, n1, FA_CREATE_NEW | FA_WRITE);
    Serial.print(" create_fr="); Serial.print((int)r);
    if (r == FR_OK) {
        r = f_write(&f, "LTEST-DAYVAULT", 14, &wr);
        Serial.print(" write_fr="); Serial.print((int)r);
        f_close(&f);
    }
    int found = 0;
    if (f_opendir(&dir, "0:/") == FR_OK) {
        while (f_readdir(&dir, &fno) == FR_OK && fno.fname[0]) {
            if (strcmp(fno.fname, "LTEST-20260809-1110_5m32s.WAV") == 0) found = 1;
        }
        f_closedir(&dir);
    }
    Serial.print(" readdir_found="); Serial.println(found);
    r = f_rename(n1, n2);
    Serial.print(" rename_fr="); Serial.print((int)r);
    r = f_unlink(n2);
    Serial.print(" unlink_fr="); Serial.println((int)r);
}

static void record_test(int seconds)
{
    WavConfig cfg;
    cfg.format = 1;
    cfg.sample_rate = pdm_output_rate_hz();
    cfg.channels = AUDIO_CHANNELS;
    cfg.bits = AUDIO_BITS;
    cfg.block_align = (uint16_t)(AUDIO_CHANNELS * (AUDIO_BITS / 8u));
    cfg.byte_rate = cfg.sample_rate * cfg.block_align;

    FIL f;
    static uint8_t blk[512];
    static uint8_t wav_hdr_buf[44];
    uint8_t* hdr = wav_hdr_buf;
    uint32_t data_bytes = 0;
    UINT wr = 0;

    Serial.print("REC start fs=");
    Serial.print(fs_mount_result());
    if (f_open(&f, "/REC001.WAV", FA_CREATE_ALWAYS | FA_WRITE) != FR_OK) {
        Serial.println(" open FAIL");
        return;
    }
    wav_build_header(hdr, &cfg, 0);
    if (f_write(&f, hdr, 44, &wr) != FR_OK || wr != 44) { Serial.println(" hdr FAIL"); f_close(&f); return; }
    Serial.println();

    ringbuf_init(&audio_rb, audio_buf, sizeof(audio_buf));
    pdm_init(&audio_rb);
    Serial.println(" init ok");
    pdm_start();
    Serial.println(" start ok");
    Serial.print(" APB2ENR="); Serial.print(RCC->APB2ENR, HEX);
    Serial.print(" CCIPR="); Serial.print(RCC->CCIPR, HEX);
    Serial.print(" FLTCR1="); Serial.print(DFSDM1_Filter1->FLTCR1, HEX);
    Serial.print(" start_ret="); Serial.print(pdm_start_result());
    Serial.print(" FLTISR="); Serial.println(DFSDM1_Filter1->FLTISR, HEX);

    uint32_t end = millis() + (uint32_t)seconds * 1000u;
    uint8_t chunk[64];
    size_t chunk_len = 0;
    while (millis() < end) {
        dbg_iwdg_kick();
        int16_t s;
        while (pdm_try_read_sample(&s)) {
            chunk[chunk_len++] = (uint8_t)s;
            chunk[chunk_len++] = (uint8_t)(s >> 8);
            if (chunk_len == sizeof(chunk)) {
                if (f_write(&f, chunk, (UINT)chunk_len, &wr) != FR_OK || wr != chunk_len) { chunk_len = 0; goto done; }
                data_bytes += wr;
                chunk_len = 0;
            }
        }
    }
done:
    if (chunk_len > 0) {
        if (f_write(&f, chunk, (UINT)chunk_len, &wr) == FR_OK) data_bytes += wr;
    }
    pdm_stop();
    wav_patch_sizes(hdr, data_bytes);
    if (f_lseek(&f, 0) == FR_OK) f_write(&f, hdr, 44, &wr);
    f_close(&f);

    Serial.print("REC done bytes=");
    Serial.print(data_bytes);
    Serial.print(" samples=");
    Serial.print(pdm_sample_count());
    Serial.print(" overruns=");
    Serial.println(pdm_overruns());
}

static void sample_stats(void)
{
    int16_t mn = 32767, mx = -32768, prev = 0;
    long sum = 0;
    uint32_t count = 0, changes = 0;

    ringbuf_init(&audio_rb, audio_buf, sizeof(audio_buf));
    pdm_init(&audio_rb);
    pdm_start();
    uint32_t end = millis() + 3000;
    while (millis() < end) {
        dbg_iwdg_kick();
        int16_t s;
        while (pdm_try_read_sample(&s)) {
            if (count == 0) prev = s;
            else if (s != prev) { changes++; prev = s; }
            if (s < mn) mn = s;
            if (s > mx) mx = s;
            sum += s;
            count++;
        }
    }
    pdm_stop();
    Serial.print("SAMP count="); Serial.print(count);
    Serial.print(" min="); Serial.print(mn);
    Serial.print(" max="); Serial.print(mx);
    Serial.print(" avg="); Serial.print((int)(count ? sum / count : 0));
    Serial.print(" changes="); Serial.println(changes);
}

static void download_file(const char* fname)
{
    FIL f;
    uint8_t buf[512];
    UINT rd = 0;
    char path[32];

    Serial.print("DL mount="); Serial.println(fs_mount_result());
    snprintf(path, sizeof(path), "0:/%s", fname);
    if (f_open(&f, path, FA_READ) != FR_OK) { Serial.println("DL open FAIL"); return; }
    Serial.print("DLSTART ");
    Serial.println((uint32_t)f_size(&f));
    uint32_t total_read = 0, total_written = 0;
    while (f_read(&f, buf, sizeof(buf), &rd) == FR_OK && rd > 0) {
        dbg_iwdg_kick();
        total_read += rd;
        total_written += (uint32_t)Serial.write(buf, rd);
    }
    f_close(&f);
    Serial.print("DLEND read="); Serial.print(total_read);
    Serial.print(" wr="); Serial.println(total_written);
}

static bool serial_write_all(const uint8_t* data, size_t length)
{
    size_t offset = 0;
    uint32_t last_progress = millis();
    while (offset < length) {
        dbg_iwdg_kick();
        const size_t written = Serial.write(data + offset, length - offset);
        if (written > 0) {
            offset += written;
            last_progress = millis();
        } else if ((millis() - last_progress) >= 10000u) {
            return false;
        } else {
            delay(1);
        }
    }
    return true;
}
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
void loop()
{
    static uint32_t last_tick = 0;
    static int last_usb = -1;
    static int usb_pending = -1;
    static uint32_t usb_pending_since = 0;
    static uint8_t low_power_latched = 0;
    static uint32_t last_bat_ms = 0;
    static uint32_t low_secs = 0;

loop_restart:
    dbg_iwdg_kick();

    if (low_power_latched) {
        /* Do not restart on unloaded voltage rebound. A latched battery must be
           attached to USB and charged above the recovery threshold. */
        const bool usb_attached = digitalRead(PIN_USB_DETECT) == HIGH;
        if (!usb_attached) {
            low_battery_enter_stop();
            goto loop_restart;
        }
        if ((millis() - last_bat_ms) >= 1000) {
            last_bat_ms = millis();
            uint16_t mv = bat_millivolts();
            const bool valid = mv >= BAT_VALID_MIN_MV && mv <= BAT_VALID_MAX_MV;
            if (valid && mv >= BAT_RESUME_MV) {
                low_power_latched = 0;
                bat_hist_reset();
                low_secs = 0;
            }
        }
    } else if ((millis() - last_bat_ms) >= 1000) {
        last_bat_ms = millis();
        uint16_t mv = bat_millivolts();
        const bool valid = mv >= BAT_VALID_MIN_MV && mv <= BAT_VALID_MAX_MV;
        if (valid) bat_hist_push(mv);
        uint16_t avg = valid ? bat_win_avg() : 0xFFFFu;
        /* each second, look at the previous-10 s average; it must stay below the
           threshold for BAT_SLEEP_SECS continuous seconds before sleeping */
        if (avg != 0xFFFFu && avg < BAT_SLEEP_MV && digitalRead(PIN_USB_DETECT) == LOW) {
            if (low_secs < 200u) low_secs++;
            if (low_secs >= BAT_SLEEP_SECS) {
                low_power_latched = 1;
                low_battery_enter_stop();
                low_secs = 0;
                goto loop_restart;
            }
        } else {
            low_secs = 0;
        }
    }

    if (Serial.available()) {
        static char line[128];
        static size_t n = 0;
        while (Serial.available()) {
            char c = (char)Serial.read();
            if (c == '\n' || c == '\r') {
                if (n > 0) {
                    line[n] = 0;
                    if (strncmp(line, "LIST", 4) == 0) {
                        DIR dir; FILINFO fno;
                        Serial.print("LIST mount="); Serial.println(fs_mount_result());
                        if (f_opendir(&dir, "0:/") == FR_OK) {
                            while (f_readdir(&dir, &fno) == FR_OK && fno.fname[0]) {
                                if ((fno.fattrib & AM_DIR) == 0) {
                                    Serial.print("  "); Serial.print(fno.fname);
                                    Serial.print(" "); Serial.println((uint32_t)fno.fsize);
                                }
                            }
                            f_closedir(&dir);
                        }
                        Serial.println("LIST done");
                    } else                     if (strncmp(line, "DMAT", 4) == 0) {
                        if (rec_active) rec_stop();
                        dbg_step_set(10);
                        pdm_init(&audio_rb);
                        dbg_step_set(20);
                        pdm_start();
                        dbg_step_set(30);
                        uint32_t e = millis() + 2000;
                        uint32_t cnt = 0;
                        uint32_t lo = 0xFFFFFFFF;
                        int64_t ssum = 0, ssq = 0;
                        int32_t mn = 32767, mx = -32768;
                        while (millis() < e) {
                            dbg_iwdg_kick();
                            int16_t tmp[256];
                            int n = pdm_dma_read(tmp, 256);
                            cnt += (uint32_t)n;
                            for (int i = 0; i < n; i++) {
                                ssum += tmp[i];
                                ssq += (int64_t)tmp[i] * tmp[i];
                                if (tmp[i] < mn) mn = tmp[i];
                                if (tmp[i] > mx) mx = tmp[i];
                            }
                            if (n < lo) lo = (uint32_t)n;
                            if (millis() % 250 == 0) dbg_step_set(40);
                        }
                        dbg_step_set(50);
                        uint32_t ch = 0;
                        int32_t halv = (int32_t)(DFSDM1_Filter1->FLTRDATAR & 0xFFFFu);
                        int32_t rms = (cnt > 0) ? (int32_t)sqrt((double)ssq / cnt) : 0;
                        Serial.print("DMAT cnt="); Serial.print(cnt);
                        Serial.print(" rms="); Serial.print(rms);
                        Serial.print(" dc="); Serial.print((int32_t)(ssum / (cnt ? (int64_t)cnt : 1)));
                        Serial.print(" mn="); Serial.print(mn); Serial.print(" mx="); Serial.print(mx);
                        Serial.print(" hal="); Serial.print(halv);
                        Serial.print(" ndtr="); Serial.print(DMA1_Channel5->CNDTR);
                        Serial.print(" start="); Serial.print(pdm_start_result());
                        Serial.println();
                        pdm_stop();
                        dbg_step_set(0);
                    } else if (strncmp(line, "ITST", 4) == 0) {
                        if (rec_active) rec_stop();
                        pdm_itst_start();
                        uint32_t e = millis() + 2000;
                        while (millis() < e) { dbg_iwdg_kick(); }
                        Serial.print("ITST isr="); Serial.println(pdm_isr_count_now());
                        pdm_stop();
                    } else if (strncmp(line, "SAMP", 4) == 0) {
                        if (rec_active) rec_stop();
                        sample_stats();
                    } else if (strncmp(line, "DOWNLOAD ", 9) == 0) {
                        download_file(line + 9);
                    } else if (strcmp(line, "BULKSPEED") == 0) {
                        if (rec_active) rec_stop();
                        transfer_workspace_busy = true;
                        benchmark_winusb();
                        transfer_workspace_busy = false;
                    } else if (strncmp(line, "BULK2 ", 6) == 0) {
                        char request_line[128];
                        snprintf(request_line, sizeof(request_line),
                                 "GET2 %s", line + 6);
                        ExportRequest request;
                        if (export_parse_get2(request_line, &request)) {
                            if (rec_active) rec_stop();
                            transfer_workspace_busy = true;
                            download_file_bulk2(&request);
                            transfer_workspace_busy = false;
                        } else {
                            Serial.println("BULK2FAIL reason=request");
                        }
                    } else if (strncmp(line, "GET2 ", 5) == 0) {
                        ExportRequest request;
                        if (export_parse_get2(line, &request)) {
                            if (rec_active) rec_stop();
                            transfer_workspace_busy = true;
                            download_file_get2(&request);
                            transfer_workspace_busy = false;
                        } else Serial.println("GET2FAIL reason=request");
                    } else if (strncmp(line, "DL2 ", 4) == 0) {
                        if (rec_active) rec_stop();
                        transfer_workspace_busy = true;
                        download_file2(line + 4);
                        transfer_workspace_busy = false;
                    } else if (strcmp(line, "OPUSSTAT") == 0) {
                        opusstat_print();
                    } else if (strncmp(line, "REC", 3) == 0 && line[3] != ' ') {
                        rec_start();
                        if (rec_active) {
                            Serial.print("REC started seq="); Serial.print(rec_seq);
                            Serial.print(" name="); Serial.println(rec_name);
                        } else {
                            Serial.print("REC start FAIL err=");
                            Serial.println(CompressedRecorder::result_name(
                                (CompressedRecorderResult)rec_err));
                        }
                    } else if (strncmp(line, "STOP", 4) == 0) {
                        rec_stop();
                    } else if (strncmp(line, "CHECK", 5) == 0) {
                        check_wav_file();
                    } else if (strncmp(line, "CIRC", 4) == 0) {
                        fs_mount_result();
                        uint64_t fb = fs_free_bytes();
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

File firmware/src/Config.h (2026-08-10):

#pragma once
#include "stm32l4xx_hal.h"
#include "PdmRate.h"

#define PIN_SD_CS       GPIO_PIN_4
#define PIN_SD_CS_PORT  GPIOA
#define PIN_SD_SCK      GPIO_PIN_5
#define PIN_SD_MISO     GPIO_PIN_6
#define PIN_SD_MOSI     GPIO_PIN_7

#define PIN_USB_DETECT_PIN   GPIO_PIN_9
#define PIN_USB_DETECT_PORT  GPIOA

#define PIN_PDM_CLK       GPIO_PIN_2
#define PIN_PDM_CLK_PORT  GPIOC
#define PIN_PDM_DATA      GPIO_PIN_12
#define PIN_PDM_DATA_PORT GPIOB

#define PDM_CKOUT_DIVIDER PDM_PRODUCTION_CKOUT_DIVIDER
#define PDM_OSR           PDM_PRODUCTION_OSR
#define PDM_GAIN          128u
#define PDM_HALF_SAMPLES  512u
#define PDM_RING_BYTES    (PDM_HALF_SAMPLES * 2u * 8u)   /* 8 KB ring */

#if PDM_CKOUT_DIVIDER == 0u
#error "PDM_CKOUT_DIVIDER must be non-zero"
#endif

#if PDM_OSR == 0u
#error "PDM_OSR must be non-zero"
#endif

#if PDM_CLOCK_HZ(PDM_DFSDM_SOURCE_HZ, PDM_CKOUT_DIVIDER) < 1100000u || \
    PDM_CLOCK_HZ(PDM_DFSDM_SOURCE_HZ, PDM_CKOUT_DIVIDER) > 4800000u
#error "PDM clock must remain in the SPH0655 normal-mode range"
#endif

#define AUDIO_SAMPLE_RATE PDM_PCM_RATE_HZ(PDM_DFSDM_SOURCE_HZ, PDM_CKOUT_DIVIDER, PDM_OSR)
#define AUDIO_CHANNELS    1u
#define AUDIO_BITS        16u

static_assert(AUDIO_SAMPLE_RATE == 16000u,
              "Opus recording requires exact 16 kHz PCM");

#define REC_DIR_STR "REC"
#define REC_EXT_STR "OPUS"
#define REC_SEQ_MAX 999u

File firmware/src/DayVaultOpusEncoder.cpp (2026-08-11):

#include "DayVaultOpusEncoder.h"

#include <limits.h>

#include <opus.h>

#include "OpusArena.h"

namespace {

const size_t kMaximumWorkspaceBytes = 32u * 1024u;

}  // namespace

DayVaultOpusEncoder::DayVaultOpusEncoder()
    : encoder_(nullptr),
      lookahead_samples_16k_(0u),
      pre_skip_48k_(0u),
      workspace_used_(0u),
      stats_{}
{
}

DayVaultOpusEncoder::~DayVaultOpusEncoder()
{
    end();
}

bool DayVaultOpusEncoder::begin(void* workspace, size_t bytes)
{
    end();
    lookahead_samples_16k_ = 0u;
    pre_skip_48k_ = 0u;
    workspace_used_ = 0u;
    stats_ = DayVaultOpusStats{};

    if (workspace == nullptr || bytes == 0u) {
        ++stats_.error_count;
        return false;
    }

    opus_arena_begin(workspace, bytes);
    int error = OPUS_OK;
    encoder_ = opus_encoder_create(kOpusSampleRate, 1,
                                   OPUS_APPLICATION_RESTRICTED_SILK, &error);
    workspace_used_ = opus_arena_used();
    if (encoder_ == nullptr || error != OPUS_OK) return fail_begin();
    if (workspace_used_ > bytes || workspace_used_ > kMaximumWorkspaceBytes) {
        return fail_begin();
    }

    if (opus_encoder_ctl(encoder_, OPUS_SET_BITRATE(kOpusBitrate)) != OPUS_OK) {
        return fail_begin();
    }
    if (opus_encoder_ctl(encoder_, OPUS_SET_VBR(1)) != OPUS_OK) {
        return fail_begin();
    }
    if (opus_encoder_ctl(encoder_, OPUS_SET_VBR_CONSTRAINT(1)) != OPUS_OK) {
        return fail_begin();
    }
    if (opus_encoder_ctl(encoder_, OPUS_SET_COMPLEXITY(kOpusComplexity)) != OPUS_OK) {
        return fail_begin();
    }
    if (opus_encoder_ctl(encoder_, OPUS_SET_SIGNAL(OPUS_SIGNAL_VOICE)) != OPUS_OK) {
        return fail_begin();
    }
    if (opus_encoder_ctl(encoder_, OPUS_SET_DTX(0)) != OPUS_OK) {
        return fail_begin();
    }
    if (opus_encoder_ctl(encoder_, OPUS_SET_INBAND_FEC(0)) != OPUS_OK) {
        return fail_begin();
    }
    if (opus_encoder_ctl(encoder_, OPUS_SET_PACKET_LOSS_PERC(0)) != OPUS_OK) {
        return fail_begin();
    }
    if (opus_encoder_ctl(encoder_, OPUS_SET_MAX_BANDWIDTH(OPUS_BANDWIDTH_WIDEBAND)) != OPUS_OK) {
        return fail_begin();
    }

    opus_int32 lookahead = 0;
    if (opus_encoder_ctl(encoder_, OPUS_GET_LOOKAHEAD(&lookahead)) != OPUS_OK) {
        return fail_begin();
    }
    if (lookahead <= 0 || lookahead > UINT16_MAX / 3) return fail_begin();

    lookahead_samples_16k_ = (uint16_t)lookahead;
    pre_skip_48k_ = (uint16_t)(lookahead_samples_16k_ * 3u);
    workspace_used_ = opus_arena_used();
    if (workspace_used_ > bytes || workspace_used_ > kMaximumWorkspaceBytes) {
        return fail_begin();
    }
    return true;
}

int DayVaultOpusEncoder::encode(const int16_t pcm[kOpusFrameSamples],
                                uint8_t packet[kOpusMaxPacketBytes])
{
    if (encoder_ == nullptr) {
        ++stats_.error_count;
        return OPUS_INVALID_STATE;
    }
    if (pcm == nullptr || packet == nullptr) {
        ++stats_.error_count;
        return OPUS_BAD_ARG;
    }

    const int length = opus_encode(encoder_, pcm, kOpusFrameSamples,
                                   packet, kOpusMaxPacketBytes);
    if (length <= 0 || length > kOpusMaxPacketBytes ||
        opus_arena_used() != workspace_used_) {
        ++stats_.error_count;
        return length < 0 ? length : OPUS_INTERNAL_ERROR;
    }

    ++stats_.frame_count;
    stats_.encoded_bytes += (uint32_t)length;
    return length;
}

uint16_t DayVaultOpusEncoder::lookahead_samples_16k() const
{
    return lookahead_samples_16k_;
}

uint16_t DayVaultOpusEncoder::pre_skip_48k() const
{
    return pre_skip_48k_;
}

size_t DayVaultOpusEncoder::workspace_used() const
{
    return workspace_used_;
}

DayVaultOpusStats DayVaultOpusEncoder::stats() const
{
    return stats_;
}

void DayVaultOpusEncoder::end()
{
    if (encoder_ != nullptr) opus_encoder_destroy(encoder_);
    encoder_ = nullptr;
}

bool DayVaultOpusEncoder::fail_begin()
{
    workspace_used_ = opus_arena_used();
    if (encoder_ != nullptr) opus_encoder_destroy(encoder_);
    encoder_ = nullptr;
    lookahead_samples_16k_ = 0u;
    pre_skip_48k_ = 0u;
    ++stats_.error_count;
    return false;
}

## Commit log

2026-08-06 feat(firmware): add LSE RTC driver with backup-register validity
2026-08-06 feat(firmware): add battery ADC and USB_DETECT GPIO drivers
2026-08-06 feat(firmware): add SPI microSD driver and FatFs glue
2026-08-06 fix(firmware): correct SPI BR divider encoding for SD speed selection
2026-08-06 feat(firmware): add mono DFSDM PDM capture with DMA ping-pong skeleton
2026-08-06 feat(firmware): add power state machine with host tests
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2026-08-06 fix(firmware): start/stop DFSDM per power state, correct standby wake vs IWDG, preallocate segments
2026-08-06 fix(firmware): encapsulate RTC wakeup timer in hw_rtc, drop raw handle exposure
2026-08-07 feat(firmware): add PlatformIO scaffold, L452RC board, and usbproto line parser
2026-08-07 feat(firmware): add clock tree and USB CDC device stack
2026-08-07 feat(firmware): wire CDC DFU command to system-memory bootloader jump
2026-08-07 docs: correct build_src_filter in USB DFU plan (+<*> needed, filter replaces default)
2026-08-07 feat(firmware): add stereo PCM WAV module with host tests; enable DMA/DFSDM/SPI HAL
2026-08-07 docs: fix golden-byte sample-rate typo in recording plan (16000 Hz = 0x3E80 LE)
2026-08-07 feat(firmware): vendor FatFs and add SPI1 microSD driver with FatFs glue
2026-08-07 feat(firmware): add DFSDM stereo PDM capture with DMA
2026-08-07 feat(firmware): add USB MSC read-only block device and CDC/MSC runtime switch
2026-08-07 feat(firmware): integrate recording pump with USB attach/detach switch
2026-08-07 fix(firmware): ST USB VID 0x0483; add BOOT0-pin software DFU trigger
2026-08-07 docs: add HARD RULES — never modify boot-config option bytes (protect DFU entry)
2026-08-07 fix(firmware): USB clock via HSI48; add USBD_LL_Delay and PCD config; use DEVICE_FS
2026-08-08 docs: add Arduino recorder design (USB auto start/stop, CDC+MSC, worktree split)
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2026-08-08 wip(firmware): arduino_test bring-up probe (moved to legacy worktree next)
2026-08-08 feat(arduino): project skeleton with 80MHz/HSI48 clock and LED blink
2026-08-08 feat(arduino): USB CDC console with boot diagnostic banner
2026-08-08 fix(arduino): enable VDDUSB supply so USB enumerates
2026-08-08 fix(arduino): mux PA11/12 to USB AF, CDC device class, PCD init check
2026-08-08 feat(arduino): native USB CDC serial console with boot banner (step1)
2026-08-08 feat(arduino): serial commands INFO/DFU; software DFU jump (step2)
2026-08-08 feat(arduino): SPI1 SD card driver, SD command reports 128GB capacity (step3)
2026-08-08 feat(arduino): FatFs exFAT mount+write+readback verified on 128GB card (step4)
2026-08-08 feat(arduino): DFSDM mono PDM capture to exFAT SD via polling, 16kHz (step5)
2026-08-08 feat(arduino): CHECK command verifies recorded WAV (mono 16kHz valid)
2026-08-08 feat(arduino): auto-record USB start/stop, fix WAV header, boot-with-USB-detached auto-start, REC/STOP commands (step6)
    [main.cpp]
2026-08-08 feat(arduino): DOWNLOAD serial command streams WAV file to PC
2026-08-08 fix(arduino): don't double-shift DFSDM sample (was losing 8 bits of resolution)
    [PdmCapture.cpp, main.cpp]
2026-08-08 feat(arduino): dynamic WAV sample rate matches actual capture; revert to polling capture (interrupt storm unresolved, documented)
    [Config.h, PdmCapture.cpp, main.cpp]
2026-08-08 fix(arduino): remove blocking tick print during recording; discard startup samples
    [main.cpp]
2026-08-08 chore: revert OSR to 64 (signal level); keep interrupt diagnostics (ITST)
    [PdmCapture.cpp, main.cpp]
2026-08-08 feat: DMA capture fixes bass-only audio (45kHz uniform sampling)
    - Root cause: polling capture froze DFSDM filter during SD writes -> non-uniform sampling -> band-limited to 5.5kHz (bass only)
    - Fix: DMA1_Channel5 (CSELR=0, DFSDM1_FLT1 on L4x2 direct-request DMA) + FastMode -> 45kHz uniform capture
    - Discovered L452 has NO DMAMUX (F4-style CSELR DMA); DMAMUX writes caused hard faults
    - SD write AND read busy-waits: 64-byte -> time-based 100ms
    - Download: chunked ACK protocol (DL2), IWDG kick during download, USB_CDC_TRANSMIT_TIMEOUT=10000
    - Debug: IWDG watchdog (5s), HardFault PC capture, DBG command, DMAT/DSCAN diagnostics
    [PdmCapture.cpp, SdCard.cpp, main.cpp]
2026-08-08 fix: DMA data extraction - read FLTRDATAR[31:16] not low 16 bits
    Root cause of all-noise: FLTRDATAR RDATA is 24-bit data in bits 31:8 (left-aligned). PSIZE=16 read of the base address got bits 15:0 = data low byte + channel bits = garbage -> full-scale noise (rms 17768).
    Fix: DMA CPAR offset +2 reads FLTRDATAR[31:16] (significant 16 bits of the 24-bit data). Applied PDM_GAIN=256 (matches polling path level). Result: clean audio, rms 952, full spectrum to 8kHz, no noise.
    [Config.h, PdmCapture.cpp, main.cpp]
2026-08-08 fix: high-pass filter removes DC drift low-frequency rumble
    Analysis showed window DC drifted -922 to -130 (std 118) -> 43.7% of quiet-segment energy below 200Hz = audible low rumble. Added first-order HPF (~100Hz, Q15) in DMA read path. Sub-200Hz energy: 43.7% -> 16.7%, DC std 118 -> 3.1.
    [PdmCapture.cpp, main.cpp]
2026-08-08 feat: dual-mic capture infra + OSR128 + 150Hz HPF noise cleanup
    - Add Channel0 (CHINSEL redirect, falling edge) + Filter0 for 2nd mic U2
    - Second DMA (DMA1_Ch4) for Filter0; found U2 is 7x louder (mismatch) -> record U1 mono
    - OSR 64->128: sample rate 15.7k->7.9k, eliminates high-freq hiss (bandwidth 3.9k, voice)
    - HPF tuned for 7.9kHz sample rate ~150Hz cutoff: removes 50-60Hz mains hum
    - Results: sub-200Hz 32.9%->9%, energy concentrated in voice band 200-1k
    [Config.h, PdmCapture.cpp, main.cpp]
2026-08-08 fix: PDM clock was 1.0MHz, below SPH0655 mic spec (1.2-3.3MHz) - caused elevated noise floor
    Divider 26->17: fCKIN 1.0MHz->1.55MHz (in mic spec). Noise floor dropped 25dB (-24dB -> -49.7dB below speech peak). Also: voice processing chain (150Hz HPF + 3kHz presence EQ + AGC), noise gate removed per user request (was cutting speech), dual-mic capture infra (U2 7x louder, U1 used).
    [Config.h, PdmCapture.cpp]
2026-08-08 feat: spectral noise reduction (256-pt FFT, oversubtraction + spectral floor)
    Noise floor dropped to -76dB (from -49.7dB). Hann-windowed STFT, noise learned from first 1s + low-energy frame updates, G(k)=max(floor,1-alpha*N/P), alpha=2, floor=0.015. Reduces hiss during speech, not just in gaps. Applied in rec_poll_samples after AGC.
    [main.cpp]
2026-08-08 feat: voice enhancement - fix EQ sign for 16.1kHz, +8dB presence, stronger AGC
    - EQ coefficients were computed for 10.5kHz (w0>90, positive -2cos) but sample rate is now 16.1kHz (w0<90, negative) - the EQ was CUTTING 3kHz, dulling voice. Fixed signs.
    - Presence boost +6->+8dB, AGC max gain 8->12x, voice floor 1200->700 (distant voice gets more gain)
    - Removed spectral subtraction (dulled voice), noise-aware AGC retained
    [PdmCapture.cpp, main.cpp]
2026-08-08 feat: add 250Hz low-shelf cut (-4dB) to reduce mud, presence 3k-8k now 19% of loudest segment
    Voice chain: 150Hz HPF -> 250Hz low shelf -4dB -> 3kHz +8dB presence -> noise-aware AGC (12x speech / 3x quiet)
    [PdmCapture.cpp]
2026-08-08 feat: dual-mic averaging - scale U2 (7.6x louder) to U1 level, average for fuller clearer voice
    Loudest speech segment now 90% energy above 1kHz (was 45% low-mid). Reduces uncorrelated self-noise ~3dB and sounds fuller. Voice chain: dual-mic avg -> gain -> 150Hz HPF -> 250Hz shelf -> 3kHz +8dB presence -> slow AGC
    [PdmCapture.cpp]
2026-08-08 chore: final audio tuning - U1 mono, AGC target 20000, revert dual-mic averaging (low mic correlation adds noise)
    Stable config: PDM clock 1.55MHz (in spec), OSR 96 (16.1kHz), U1 mic, chain: gain -> 150Hz HPF -> 250Hz shelf -4dB -> 3kHz +8dB presence -> slow noise-aware AGC (8x speech/2x quiet, target 20000)
    [PdmCapture.cpp]
2026-08-08 test: 2.08MHz PDM clock (divider 13, OSR 96, 21.1kHz) - noise floor -71dB, voice captured
    2.4MHz failed (mic outputs DC, zcr=0 - no audio modulation). 2.08MHz works: raw signal healthy, voice captured, noise floor -71dB (vs -50dB at 1.55MHz). Coeffs retuned for 21.7kHz.
    [Config.h, PdmCapture.cpp, main.cpp]
2026-08-08 feat: dual presence EQ (2kHz +5dB, 3kHz +10dB) at 21.7kHz for brighter clearer voice
    2.08MHz PDM clock, OSR96, 21.1kHz sample rate, noise floor -71dB. Voice chain: HPF150 -> shelf250 -4dB -> peak2k +5dB -> peak3k +10dB -> slow AGC. Loudest segment 1k-3k now 24% (was 15%).
    [PdmCapture.cpp]
2026-08-08 build: integrate CompositeBuilder + ST MSC class (CDC+MSC composite build)
    Add USE_USBD_COMPOSITE flags and include paths for CompositeBuilder/MSC; patch usbd_cdc_if.c (ClassId=0 args), fix usbd_cdc.c ClearBuffer typo, zero device class bytes in usbd_desc.c. Compiles clean; composite not started at boot.
2026-08-08 feat(usb): register CDC+MSC composite in CDC_init (Task 3)
    Wire USBD_RegisterClassComposite for CDC (0x81/0x01/0x82) and MSC
    (0x83/0x03) in framework usbd_cdc_if.c CDC_init() with USBD_MSC_Storage_fops.
    Compiles clean (pio run -e dayvault). Not flashed (Task 4).
    Note: framework patch is external to this repo (.platformio package); see task-3-report.md.
2026-08-09 revert: USB MSC composite experiment - USB did not enumerate (device disappears from bus)
    CompositeBuilder integration + MSC storage was implemented and reviewed, but hardware test showed the composite device does not enumerate at all (no VID_0483, no unknown device). Reverting to the working audio firmware (v0.9-audio-final state). Framework patches (usbd_cdc_if.c, usbd_desc.c) reverted manually. MSC work remains in git history + plan doc for a future focused session.
2026-08-09 chore: revert MSC composite experiment (final) + clean up SD-log diagnostics
    Root cause analysis: composite firmware completes setup but USB does not enumerate; SD logging showed setup completes (A/B/C) but loop logging inconsistent (SD writes unreliable across resets). Not determinable remotely. CompositeBuilder CDC+MSC on STM32duino core is unsupported (PR#1088 pending 6yr) and fails enumeration. Restoring clean audio firmware. MSC work preserved in git history + plan doc.
    [main.cpp]
2026-08-09 fix: restore stable firmware - dbg_iwdg_kick was accidentally deleted from loop(), causing IWDG reset loop (USB reconnect every 5s)
    Root cause of continuous USB disconnect/reconnect: a debugging edit removed dbg_iwdg_kick() from loop(), so the IWDG watchdog was never refreshed after setup -> the MCU reset every ~5s -> USB dropped and re-enumerated constantly. Restored main.cpp and platformio.ini to v0.9-audio-final state. Device verified stable (uptime monotonic, no resets).
    [main.cpp]
2026-08-09 docs: add Serial Command Reference (incl. DL2 audio download protocol), link from README
    MSC disk export permanently reverted (STM32duino has no working MSC path). Serial (CDC) + software DFU confirmed working. Documented all serial commands, the DL2 chunked-ACK download protocol, and DFU entry for future development.
2026-08-09 feat: add DeviceTime RTC module (LSE-driven calendar, unix get/set, YYYY-MM-DD HH:MM:SS format)
2026-08-09 feat: add Battery module - ADC1 PA0 sense with VREFINT-calibrated VDDA, 8-sample averaged millivolts/percent
2026-08-09 feat: wire DeviceTime + Battery into main - SETTIME <unix> command, INFO reports time/bat/pct
    Additive: dt_init/bat_init after dbg_iwdg_init in setup, SETTIME branch before INFO in parser, time/bat/pct fields in INFO. Build clean (RAM 85.1%, Flash 24.4%).
2026-08-09 feat: low-battery STOP sleep (RTC 4s wake + hysteresis gate) and 100ms-debounced USB detect
2026-08-09 fix: re-enter STOP on every periodic wake while battery below RESUME
    Critical review finding: bat_asleep latch made the else-if(mv<BAT_SLEEP_MV)
    branch unreachable, so the MCU slept only once per low-battery episode and
    then ran the full loop awake on a critically-low battery.
    - Add dt_wake_off() (deactivate RTC wake-up timer) in DeviceTime.h/.cpp
    - Restructure battery gate: bat_asleep==1 branch runs on every loop pass;
    mv>=BAT_RESUME_MV resumes + dt_wake_off(), else low_battery_enter_stop()
    + goto loop_restart (re-sleep immediately, no 1s gate)
    - First-entry 3s hold path unchanged; IWDG/USB/stop/clock code untouched
    [DeviceTime.cpp, main.cpp]
2026-08-09 fix: resume from low-battery STOP on USB attach even below BAT_RESUME_MV
    [main.cpp]
2026-08-09 fix: only enter first-pass low-battery STOP sleep when USB is detached
    [main.cpp]
2026-08-09 feat(diag): add TIME command to dump raw RTC registers and LSE/LSI status
    Adds a TIME serial command for debugging the frozen RTC: prints RTC->TR/DR/SSR/CR/ISR plus LSE-ready (RCC_BDCR_LSERDY) and LSI-ON (RCC_CSR_LSION). Uses RCC_BDCR_LSERDY because RCC_CSR_LSERDY does not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
2026-08-09 docs: document SETTIME/TIME/INFO time+battery, battery/RTC/low-battery sleep behavior in Serial-Command-Reference
2026-08-09 Fix: guard VREFINT divide-by-zero and clamp RTC year to 2099
    [Battery.cpp, DeviceTime.cpp]
2026-08-09 docs: add power-loss/crash safety to RTC filename design (checkpointed header+sync, clean sleep finalize)
2026-08-09 feat(rec): timestamped recording filenames with duration rename, collision suffix, seq fallback; CHECK newest-by-name
    [main.cpp]
2026-08-09 feat(rec): periodic WAV header+f_sync checkpointing for power-loss safety; finalize recording before low-battery STOP
2026-08-09 docs: SETTZ/SETTIME tz arg, LTEST, INFO tz/time_set, timestamp+duration naming, power-loss recovery
2026-08-09 fix(rec): guard SETTIME trailing-space tz reset, NUL-terminate CHECK best, docs auto-record bullet
    [main.cpp]
2026-08-09 docs: plan Task 3 adds persistent SD mount + boot free-space warm (exFAT f_getfree ~10s first call)
2026-08-09 feat(pdm): detect DMA ring lap and resync read position (overflow self-recovery)
2026-08-09 docs: plan adds no-re-mount guard (fixes LIST-freezes-recording pre-existing bug)
2026-08-09 feat(rec): persistent SD mount + boot free-space warm; never force re-mount while mounted (fixes LIST-freezes-recording); periodic 30s circular check; rec_start pre-check; INFO free=
    [main.cpp]
2026-08-09 fix(rec): remove DL/DL2 open-fail unmount (was freezing active recording); feed IWDG in SD driver for long ops
    [SdCard.cpp, main.cpp]
2026-08-09 feat(host): serial layer - DayVault port detection + DeviceConnection + DL2 chunked-ACK download
2026-08-09 feat(host): config, per-device sync state JSON, and rotating log store
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2026-08-09 fix(host): share config dict (folder picker takes effect) and support clean QThread interruption on quit
2026-08-10 feat(host): log device add/remove/port-change and sync start/finish/error to app.log
2026-08-10 fix(dfu): software DFU now reliable - set noinit flag + reset, then jump to bootloader at setup() start (before IWDG/USB/app init) with clean clocks and USB
    [main.cpp]
2026-08-10 fix(bat): fix VREFINT channel-0 contamination, settled-sampling PA0 read, gain calibration (10s avg 1038mV->4.1V); low-battery sleep uses 20s history / 10s window average sustained 10s (sleep) and 10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
    [Battery.cpp, main.cpp]
2026-08-10 feat(host): i18n (English default, Chinese switchable), window sized to fit all columns, file list newest-first; docs
2026-08-10 fix(firmware): use full SRAM for safe transfer buffers
    [main.cpp]
2026-08-10 fix(sync): keep device visible during WinUSB transfer
2026-08-10 fix(audio): track paired PDM DMA wraps
    [PdmCapture.cpp]
2026-08-10 fix(audio): export DMA IRQ handlers
    [PdmCapture.cpp]
2026-08-10 fix(audio): synchronize valid PDM clock
    [Config.h, PdmCapture.cpp, main.cpp]
2026-08-10 fix(audio): produce exact 16 kHz PCM for Opus
    [Config.h]
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2026-08-10 fix(rec): finalize Opus recordings safely
    [CompressedRecorder.cpp, DayVaultOpusEncoder.cpp]
2026-08-11 fix(audio): remove speech-smearing noise reduction
    [main.cpp]
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2026-08-11 feat(mechanical): add printable DayVault enclosure
    [DayVault_Enclosure.blend, DayVault_FrontCover.stl, DayVault_RearShell_Clip.stl]
2026-08-11 fix(mechanical): orient rear shell for FDM printing
    [DayVault_Enclosure.blend, DayVault_RearShell_Clip.stl]
2026-08-11 fix(mechanical): make chest clip a free cantilever
    [DayVault_Enclosure.blend, DayVault_RearShell_Clip.stl]
2026-08-12 feat: finalize low-power sync and enclosure updates
    Add calibrated low-battery STOP2 handling and named device deletion. Improve the desktop sync UI with battery/charging status, recording metadata, Explorer file selection, and safe file actions. Refi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
    [DayVault_Enclosure.blend, DayVault_FrontCover.stl, DayVault_RearShell_Clip.stl]
2026-08-12 docs: refresh README with working prototype
    Show the assembled recorder and current sync application, align the English and Chinese documentation, and document the v1.1 recording, power, file-management, and release workflow.
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
